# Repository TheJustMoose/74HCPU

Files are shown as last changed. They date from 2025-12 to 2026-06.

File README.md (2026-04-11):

# 74HCPU

Not a very scary instruction set discrete logic processor.

* 8 bit data
* 16 bit address / 64KB RAM
* 17 bit address (in V register) / 128KW Dual Bank Video RAM
* 16 [instructions](#instruction-list)
* 8 data [registers](#registers) and 4 pointer registers in 2 banks
* 1 [flags register](#flags-register) in IO port
* 32 input ports and 32 output ports (You can write a constant to the first 8 ports. Only registers can be written to the remaining ports.)
* Assembled from 74HCxx series ICs!

## Soft!
[ASM](./ASM.md)
[UEMUL]()

## CPU structure
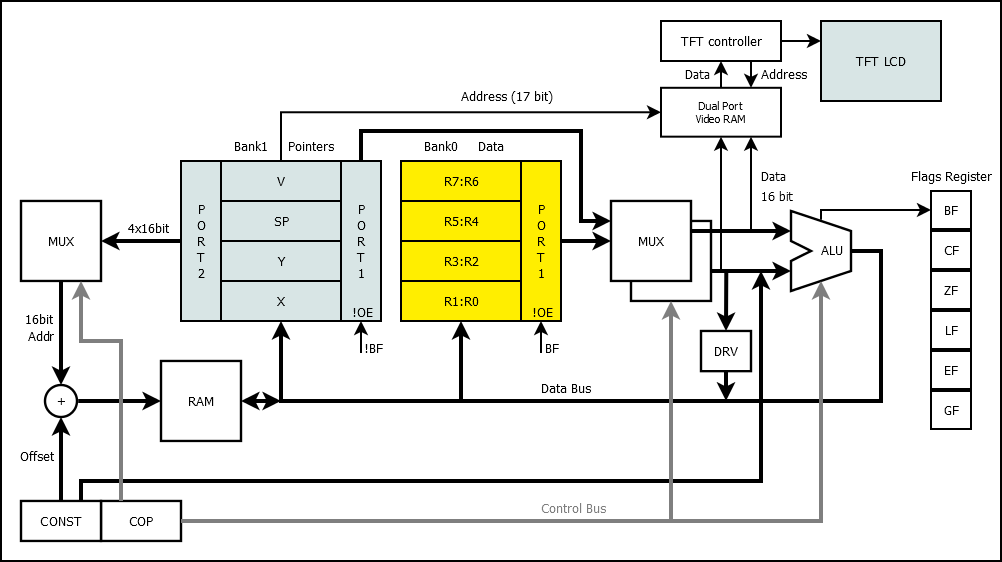
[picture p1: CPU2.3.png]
CPU structure


## How this CPU works?

CPU tacts

[Layers of PCBs](layers/README.md)

## Instruction list
*The words 'instruction' and 'command' mean the same thing.*

```
|----------------------------------------------|f|-------------------------------------------------------------|
|   HIGH BYTE    |    LOW BYTE   |  HIGH BYTE  |l|                                                             |
|F E D C  B A 9 8 7 6 5 4 3 2 1 0|   (again)   |a|                    SHORT DESCRIPTION                        |
|   4   +   3 + 1 + 3  +    5    = 16          |g|                                                             |
|----------------------------------------------|s|-------------------------------------------------------------|
|   ADD |  DST |1|    CONST or   | 01 0000 0001|*| Add a constant to a register (This is one command, not two) |
|   ADD |  DST |0| SRC |-|Z|z|I|i| 00 0000 0000|*| Add a register to a register (same OpCode, different bit 8) |
|----------------------------------------------| |-------------------------------------------------------------|
|  ADDC |  DST |C| SRC |F|Z|z|I|i| 10 0001 0000|*| ADD a constant or register and CARRY FLAG to a register     |
|   AND |  DST |C| SRC |-|Z|z|I|i| 20 0010 0000|*| Bitwise AND a constant or register with a register          |
|    OR |  DST |C| SRC |-|Z|z|I|i| 30 0011 0000|*| Bitwise OR a constant or register with a register           |
|   XOR |  DST |C| SRC |-|Z|z|I|i| 40 0100 0000|*| Bitwise XOR a constant or register with a register          |
|   MUL |  DST |C| SRC |-|Z|z|I|i| 50 0101 0000|*| MULtiply a constant or register by a register.              |
|   UNO |  DST |0|-|TYP|F|-|-|-|-| 60 0110 0000|*| Unary commands INV, SWAP, LSR, LSRC                         |
|   MOV |  DST |C| SRC |*|Z|z|I|i| 70 0111 0000| | MOV a constant or register to a register                    |
|   LPM |  DST |0|EXT|D|U|-|-|-|W| 80 1000 0000| | Load Program Memory - Read data from [commands] ROM         |
|    LD |  DST |V|EXT|D|U|OFFSET4| 90 1001 0000| | LoaD data from RAM to a register                            |
|    IN |  DST |  PORT   |Z|z|I|i| A0 1010 0000| | INput data from port to a register                          |
|--------------|8-7-6-5-4|-------|-------------| |-------------------------------------------------------------|
|   OUT | PORT |1|    CONST or   | B1 1011 0001| | Output const to a port (This is one command, not two)       |
|   OUT | PORT |0| SRC |PRT|X|O|o| B0 1011 0000| | Output register to a port (same OpCode, different bit 8)    |
|----------------------------------------------| |-------------------------------------------------------------|
|    ST |  SRC |V|EXT|D|U|OFFSET4| C0 1100 0000| | STore a register to a RAM                                   |
|   CMP |  DST |C| SRC |-|   -   | D0 1101 0000|+| CoMPare a constant or register with a register              |
|  CMPC |  DST |C| SRC |-|   -   | E0 1110 0000|+| Check flags then execute CMP                                |
| BRNCH |  CALL  | 8 bit OFFSET  | F0 1111 0000| | CALL a function with a relative address (offset)            |
| BRNCH |   JMP  | 8 bit OFFSET  | F1 1111 0001| | JMP to a relative address                                   |
| BRNCH |   RET  | 8 bit +STACK  | F2 1111 0010| | RETurn from function                                        |
| BRNCH |  RETI  | 8 bit OFFSET  | F3 1111 0011| | RETurn from Interrupt                                       |
| BRNCH |    JL  | 8 bit OFFSET  | F4 1111 0100| | Jump if Less                                                |
| BRNCH |    JE  | 8 bit OFFSET  | F5 1111 0101| | Jump if Equal                                               |
| BRNCH |   JNE  | 8 bit OFFSET  | F6 1111 0110| | Jump if Not Equal                                           |
| BRNCH |    JG  | 8 bit OFFSET  | F7 1111 0111| | Jump if greater                                             |
| BRNCH |    JZ  | 8 bit OFFSET  | F8 1111 1000| | Jump if Zero                                                |
| BRNCH |   JNZ  | 8 bit OFFSET  | F9 1111 1001| | Jump If Not Zero                                            |
| BRNCH |    JC  | 8 bit OFFSET  | FA 1111 1010| | Jump if Carry flag is set (one)                             |
| BRNCH |   JNC  | 8 bit OFFSET  | FB 1111 1011| | Jump if Carry flag is not set (zero)                        |
| BRNCH |   JHC  | 8 bit OFFSET  | FC 1111 1100| | Jump if Half Carry is set (one)                             |
| BRNCH |  JNHC  | 8 bit OFFSET  | FD 1111 1101| | Jump if Half Carry is not set (zero)                        |
| BRNCH | AFCALL | Hi 8 bit ADDR | FE 1111 1110| | Absolute Far Call (call a function at a 16-bit address)     |
| BRNCH |NOP/STOP|   1111 111x   | FF 1111 1111| | No OPeration (LSB is 0) or STOP CPU (LSB is 1)              |
|----------------------------------------------|-|-------------------------------------------------------------|
```
\* - means ZF, CF, HCF [flags](#flags-register), \+ - means GF, EQ, LF flags

### Registers
74HCPU has two register banks.
First bank has 8 arithmetic registers.
Second bank has 4 pointers (which can be used as 8 arithmetic registers).
You can change the active bank by writing BF bit of the [flags register](#flags-register).

#### Bank0 (8 pcs 8 bits registers):
|Name|Name|
|---|---|
|R7|R6|
|R5|R4|
|R3|R2|
|R1|R0|

#### Bank1 (4 pcs 16 bit registers):
<table>
<tr>
<td>

|Name|Usage|
|---|---|
|V|Video Pointer (**17** bits)|
|SP|Stack Pointer (16 bits)|
|Y|Pointer 1 (16 bits), e.g. Destination|
|X|Pointer 0 (16 bits), e.g. Source|
16 bit pointers
</td>
<td>

|Name|Name|
|---|---|
|VH|VL|
|SPH|SPL|
|YH|YL|
|XH|XL|
or 8 bit registers
</td></tr>
</table>

Also, you can use the registers of bank 1 in the same way as bank 0: R0, R1, ... R7
(R7 will store the high half of SP, R6 the low half).

### Flags register
|Bit|Flag Name|Usage|Reason|
|---|---|---|---|
|7|-|reserved|-|
|6|BF|Bank|You can write it|
|5|GF|Greater|Compare (CMP)|
|4|~EQ|Equal (inverted)|Compare (CMP)|
|3|LF|Less|Compare (CMP)|
|2|ZF|Zero|Arithmetic|
|1|CF|Carry|Arithmetic|
|0|HCF|Half Carry|Arithmetic|

### ADD, ADDC, AND, OR, XOR, MUL are binary commands  
You can use it:  
CMD Rd, Rs  
Where Rd is destination register.  
And Rs is source register.  
These commands work like this:  
Rd := Rd CMD Rs  
For example, ADD command does this:  
ADD R0, R1 -> R0 := R0 + R1  
Also you can use immediate value:  
CMD Rd, CONST  
(You can use CONST with any command: ADD, ADDC, AND, OR, XOR, MUL, MOV...)

The only exception to the use of the Rd register is MUL command.  
A pair of registers is needed to store the multiplication results.  
For example:  
MUL R1, R2 will store result into R1:R0 pair.  
That is, R1:R0 := R1 * R2.

### MUL Examples
```
  Rd select output Pair:
      _________
  Rd /         \ Pair   Rd   Rs
     |         \/
MUL R0, R1 -> R1:R0  := R0 * R1
MUL R1, R0 -> R1:R0  := R1 * R0
MUL R1, R2 -> R1:R0  := R1 * R2
MUL R1, R7 -> R1:R0  := R1 * R7
MUL R2, R3 -> R3:R2  := R2 * R3
MUL R2, R7 -> R3:R2  := R2 * R7
....
```

#### Register pairs  
The MUL command uses the following register pairs to store result:  
R1:R0 (when Rd is R0 or R1)  
R3:R2 (when Rd is R2 or R3)  
R5:R4 (when Rd is R4 or R5)  
R7:R6 (when Rd is R6 or R7)  
Rd is used to select output register pair.

### Instruction options  
C - Low byte [of command] contains constant value (1) or options (0).  
Z - Will reset high nibble of SRC register before use.  
z - Will reset low nibble of SRC register before use.  
I - Will invert high nibble of SRC register before use.  
i - Will invert low nibble of SRC register before use.  
F - Set CF flag to TRUE while executing command.  
W - Command will work with word, not byte.  
V - Command will work with Video RAM.  
D - Down, decrease pointer after command.  
U - Up, increase pointer after command.  
OFFSET4 - 4 bit size int offset to current pointer.  
O - Out will write to high nibble of port.  
o - Out will write to low nibble of port.  
X - Out will toggle bits of port by mask in register.  
SRC - Index of source register (0-7).  
DST - Index of destination register (0-7).  
TYP - Kind of unary operation (0-3).  
EXT - Index of pointer register (0-3).  
PORT + PRT - 5 bit of port index.

### UNO - unary commands  
There are four unary commands: LSR, LSRC, INV, SWAP.  
LSR shift register bits to the right. CF flag get value of right (low) bit.  
LSRC do same, but left (high) bit get value of CF.  
SWAP simply swap the nibbles.  
INV simply invert all the bits.

### LPM - Load Program Memory  
This command read (1 byte of) data from ROM, not RAM. And this command write data to register.  
The data stores in the same ROM that stores the commands themselves.
Also you can use LPMW to read the whole 16 bit word from ROM and store data to [register pair](#register-pairs).

### LD, ST - Memory commands  
LD - LoaD data from memory  
ST - STore data to memory  
V - 0 for RAM and 1 for Video RAM  
SRC - register to read  
DST - register to write  
EXT - register pair which store pointer to memory  
D - Decrement pointer after use  
U - Increment pointer after use  
OFFSET4 - 4 bit integer offset (-8...+7)  
(CPU will read/write memory with address ptr(EXT) + OFFSET4)  
Examples:
```
LD R0, X    ; read memory data from X pointer into the R0 register
ST Y, R1    ; write data from R1 into memory with address from Y pointer
ST YI, R1   ; write data and increment Y pointer
ST YD, R1   ; write data and decrement Y pointer
ST Y+5, R1  ; write data into memory address Y+5
LDV R7, V   ; read data from Video RAM with address V and store it into R7 (R7:R6 pair)
LDV R7, V+1 ; **disabled** command, you can use displacement only with X, Y and SP pointers
```

### BRNCH - Branch commands  
CALL - call a function by offset  
AFCALL - call a function to an absolute address  
RET - return to the address stored on the stack  
RETI - return from interrupt to the address stored on the stack  
JMP - go by offset  
NOP - no operation (do nothing)  
STOP - the processor will stop executing the program  
JL, JE, JNE, JG, JZ, JNZ, JC, JNC, JHC, JNHC - conditional jump instructions  
JL - jump if less  
JE - jump if equal  
JNE - jump if not equal  
JG - jump if greater  
JZ - jump if zero  
JNZ - jump if not zero  
JC - jump if carry  
JNC - jump if not carry  
JHC - jump if half carry  
JNHC - jump if not half carry

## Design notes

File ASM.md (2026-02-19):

# 74HCPU

## ASM

ASM is assembler for 74HCPU.
You can find it [here](https://github.com/TheJustMoose/74HCPU/tree/master/soft/asm).

74HCPU assembler is similar to Intel assembler.

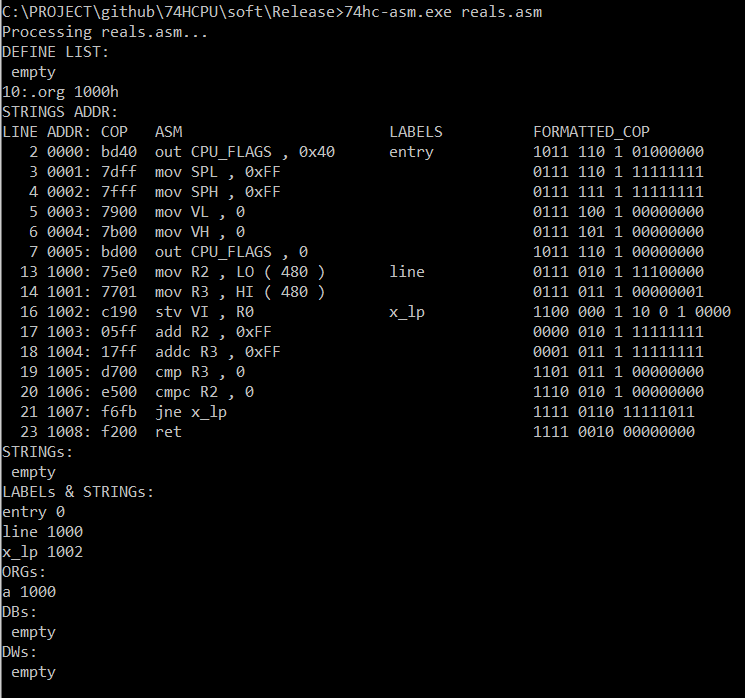
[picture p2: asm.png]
CPU asm console


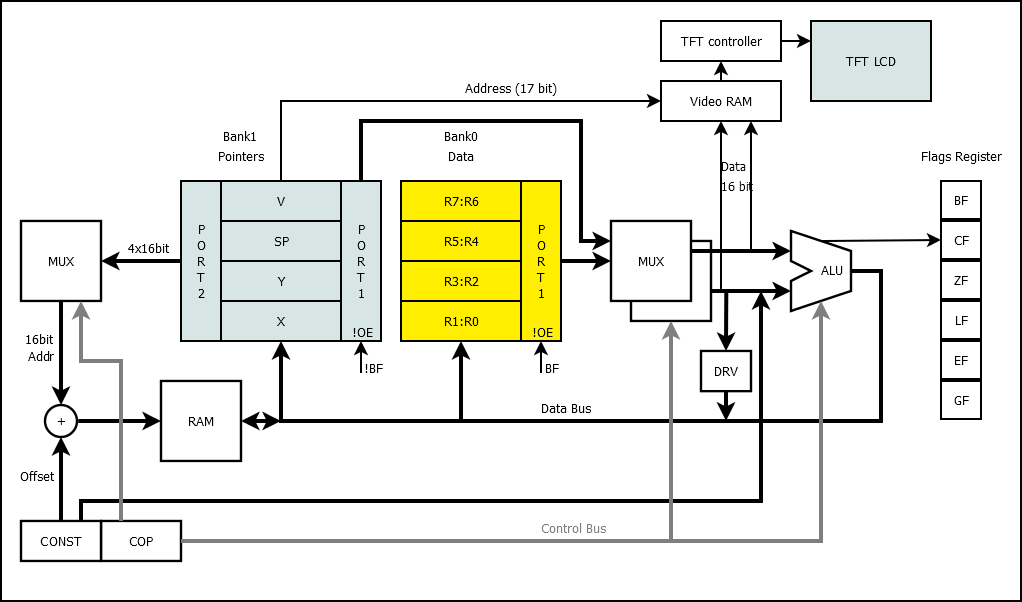
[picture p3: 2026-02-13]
CPU2.2.png

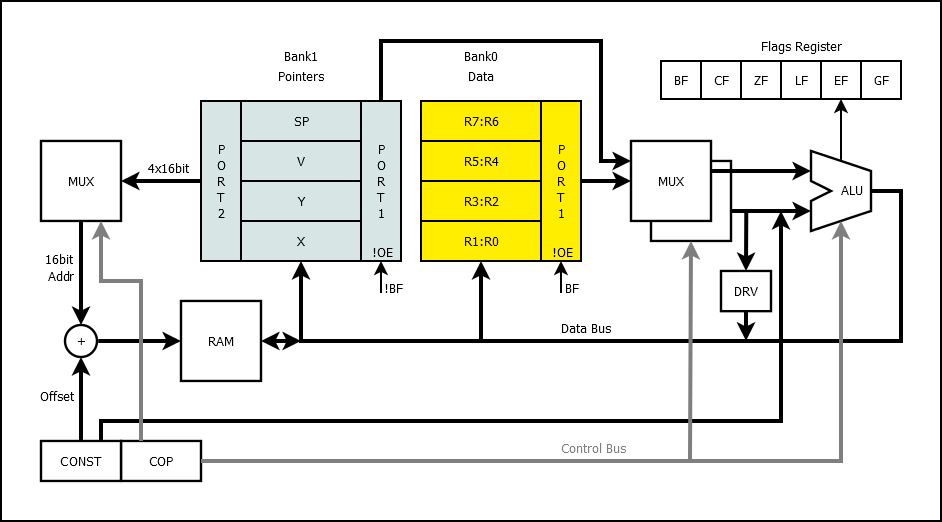
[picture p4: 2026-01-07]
CPU2.1.png

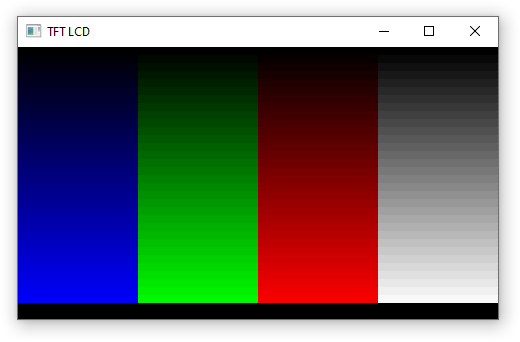
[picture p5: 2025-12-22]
soft/uemul/lcd/scr.png

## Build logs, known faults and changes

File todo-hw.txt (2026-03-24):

!!!!спаять уже всё нахрен!!!!

блин! я же совсем забыл о том, что стек то у меня есть,
 а вот счётчиков/мультиплексоров для выбора, какую ячейку читать/писать,
 я так и не дорисовал на плате
 (и триггер для фиксации stack overflow тоже нужен)

переделать MUX8:1 1bit, поменять порядок входов D0...D7
 ну и разъёмы из середины перенести в торец, чтобы избавиться от проводов

сделать торцевую плату для однобитных мультиплексоров

сделать плату для рубильников (на 8 бит)

сделать новый вариант регистра-счётчика на 8+ бит
 (хотя бы на 9, или сразу на 12, иначе выводить видео хз как)

поставить хотя бы один эксперимент с gLCD,
 например вывести на него ОДИН одноцветный прямоугольник на всю его площадь ;)

поиграть с Dual Port Video RAM

начать рисовать плату для gLCD
 (накидать туда хотя бы разъём gLCD, счётчики, генераторы)

переделать MUX2:1 так, чтобы оба входа располагались не по горизонтали, а по вертикали
         H_in     L_in     Out
 было  ........ ........ ........

         H_in     Out
 стало ........ ........
       ........
         L_in

купить запас мультиплексоров

проверить, что разъёмы плат удобно расположены

переделать плату ROM, чтобы туда намертво запаивался ZIF сокет,
 и не нужно было втыкать в разъёмы на плате переходник ZIF -> DIP,
 а уже в переходник саму ROM

начать рисовать прерывания
предусмотреть два регистра флагов - для обычной работы и работы в ISP

попробовать поковырять UART0, для начала хотя бы в виде микросхемы + Arduino!

придумать что-то с таблицей виртуальных методов,
 например сделать ICALL, или RCALL, или хз,
 как вызвать код по индексу в таблице, которая лежит в ROM
 в общем, проверить как-то, что у меня заведено в мультиплексор адреса
 (и какой вообще адрес он мультиплексирует)

условно: есть некая таблица, которая лежит в ROM
в ней есть:
addr0 - адрес виртуального метода 0
addr1 - адрес виртуального метода 1
.....

таких табличек много
адрес таблички, видимо, должен лежать в ...? в RAM, рядом со всеми данными объекта класса?
или где-то в ROM? ведь адрес таблицы не меняется после компиляции...
хотя, если есть наследование, то адрес как раз должен меняться
Оо

в любом случае, чтобы вызвать функцию/метод по индексу в табличке, можно сделать:
 берём адрес начала таблицы,
 прибавляем к нему индекс,
 читаем из этого адреса 16 бит,
 считаем эти 16 бит адресом, вызываем метод по этому адресу

альтернатива:
 располагаем перед таблицей код, который делает CALL, как раз по смещению, относительно себя
 .... а толку?

а как должен работать ICALL? брать адрес из какого-нибудь регистра?

кстати, в таблице можно располагать не абсолютные адреса,
 а саму команду CALL... и делать на эту команду JMP
  вот только не понятно, как это сделать :(

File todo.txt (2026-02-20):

ZF должен защёлкиваться по арифметическим командам, а не по CMPx
потерялись светодиоды индикации банков

проверить размер микросхем на плате регистра
проверить размер фрезы во фьюжене на плате регистра, поменять на 0.9
протравить пару регистров
набить пару регистров
набить и протестировать плату регистров
купить текстолита и лужёного провода
собрать новый фрезерный станок
купить новый монитор помельче
попробовать фрезернуть мелкую плату прям по контуру дорожек
 (только нету фрезы 0.5)
кажется, у АЛУ нет подключения шинного формирователя к BUS для команды OUT
добавить на плату АЛУ типа монтажку, ибо наверняка какой-нибудь микросхемы не хватит
добавить подписей пинов на плату АЛУ
собрать уже наконец пульт управления для проца

нарисовать свежих монтажек, с Т образным расположением площадок
(два размера, для мелких плат с флагами и для ROM)
+написать ассемблер
+написать отладчик
начать рисовать в KiCAD схемы модулей

+Proto50x70-4er
+Proto100x150
+Proto100x150-4er

07.11.2022:
+набить платы AND/OR/XOR
+набить платы MUX4:1
+пересобрать проц и протестировать
 (в результате должно стать больше места и меньше багов)
+нарисовать/заказать платы AND&ADD
 (а также новые MUX4:1 и RegLED, регистр флагов?)
+протравить/набить платы RegLED
переделать монтажку регистров на 4 платы
набить плату RegLED
+сделать плату LCD, поставить на освободившееся место!
+протравить/набить плату CMP
что-то сделать с оставшимися платами INV, MOV
+начать собирать регистр флагов на освободившемся месте
+переделать команды условных переходов О_О
добавить команды SWAP, SHL, SHR
+что-то придумать с хранением бита переноса
сделать стек поглубже
придумать уже подходящий код для тестирования!
+получить платы AND&ADD и сделать уже умножение! :))
поменять LCD 1602 на gLCD
протестировать максимальную частоту *ROFL*

перенести на плату ROM?
+перейти на 12бит коды операций? уже, фактически, 16 битные
+сделать MUX8:1?
добавить команд вычитания и т.п.?

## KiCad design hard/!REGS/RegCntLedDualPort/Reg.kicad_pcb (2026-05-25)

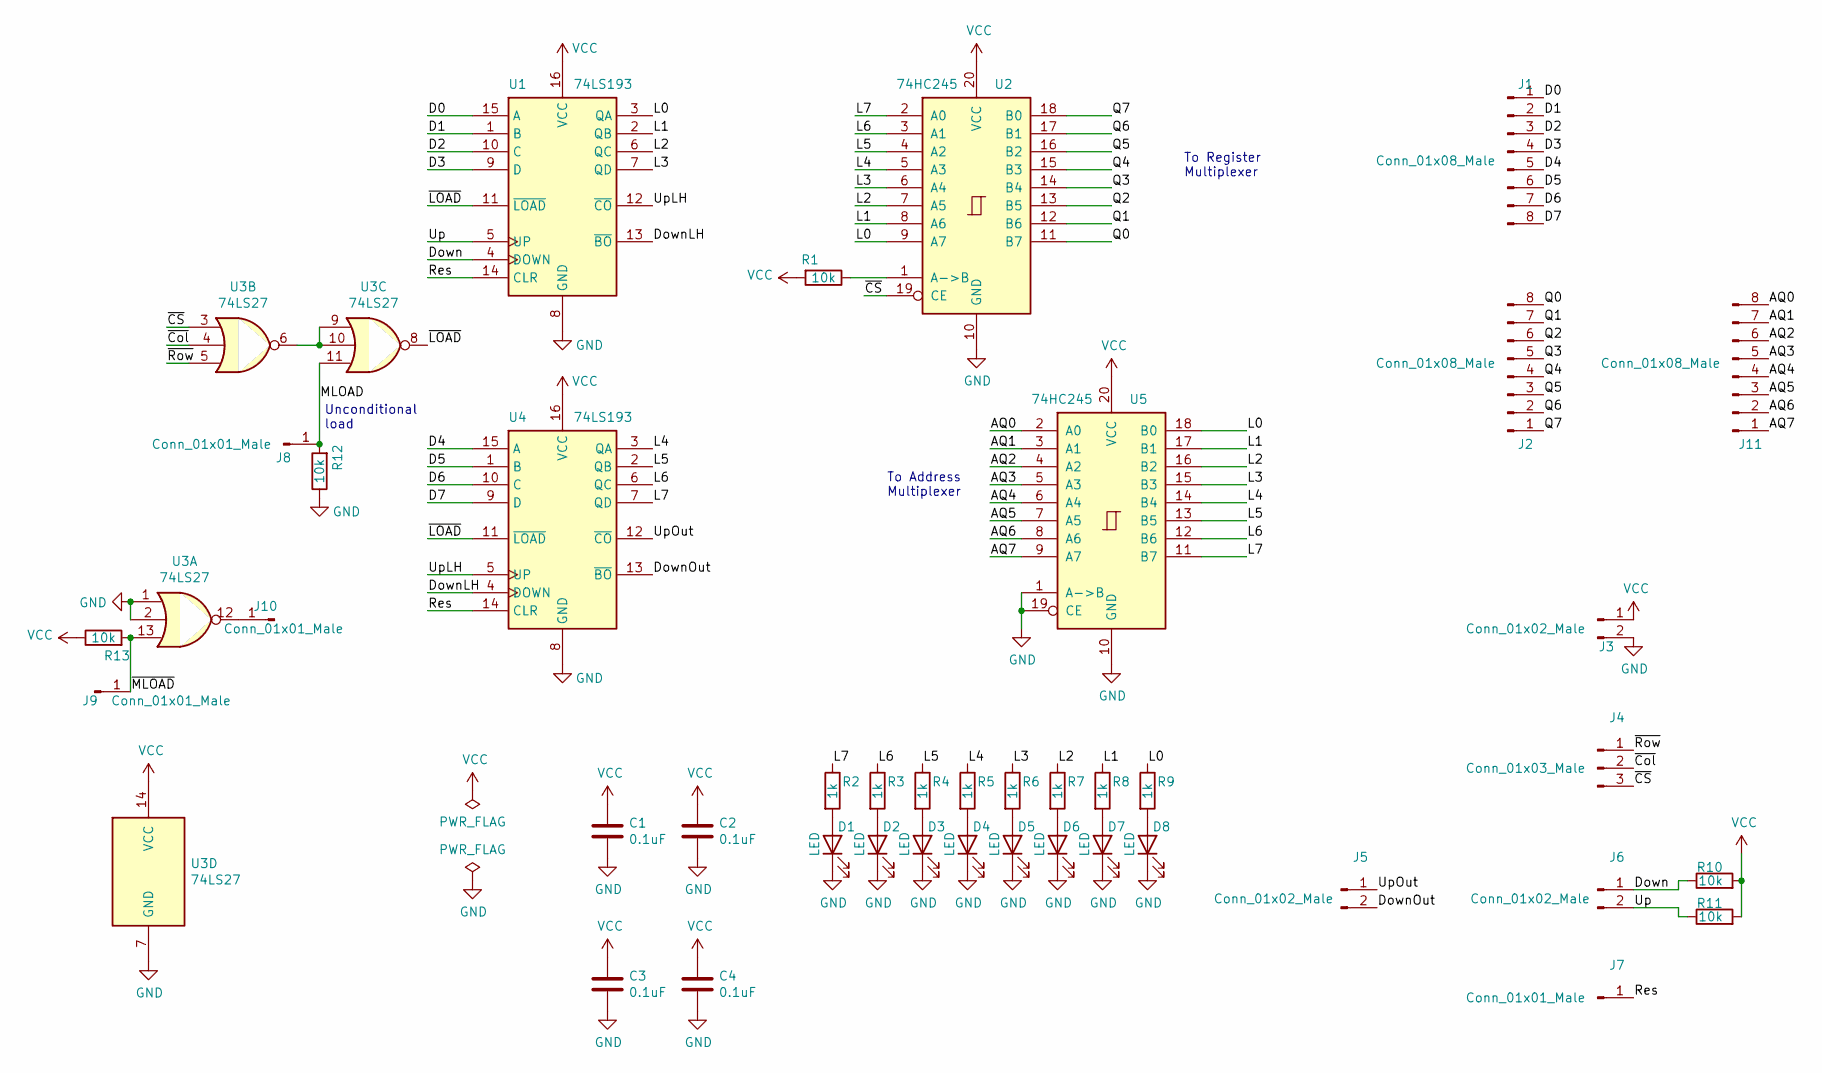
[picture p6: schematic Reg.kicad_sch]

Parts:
C1, C3: 0.1uF; C_Axial_L3.8mm_D2.6mm_P12.50mm_Horizontal
C2, C4: 0.1uF; C_0805_2012Metric_Pad1.18x1.45mm_HandSolder
D1, D2, D3, D4, D5, D6, D7, D8: LED; LED_0805_2012Metric_Pad1.15x1.40mm_HandSolder
J1, J2, J11: Conn_01x08_Male; PinHeader_1x08_P2.54mm_Horizontal
J3, J5, J6: Conn_01x02_Male; PinHeader_1x02_P2.54mm_Horizontal
J4: Conn_01x03_Male; PinHeader_1x03_P2.54mm_Horizontal
J7, J8, J9, J10: Conn_01x01_Male; PinHeader_1x01_P2.54mm_Horizontal
R1, R10, R11, R12, R13: 10k; R_0805_2012Metric_Pad1.20x1.40mm_HandSolder
R2, R3, R4, R5, R6, R7, R8, R9: 1k; R_0805_2012Metric_Pad1.20x1.40mm_HandSolder
U1, U4: 74LS193; SOP-16_3.9x9.9mm_P1.27mm
U2, U5: 74HC245; SOP-20_7.5x12.8mm_P1.27mm
U3: 74LS27; SO-14_3.9x8.65mm_P1.27mm

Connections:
/AQ0: J11.8, U5.2 (A0)
/AQ1: J11.7, U5.3 (A1)
/AQ2: J11.6, U5.4 (A2)
/AQ3: J11.5, U5.5 (A3)
/AQ4: J11.4, U5.6 (A4)
/AQ5: J11.3, U5.7 (A5)
/AQ6: J11.2, U5.8 (A6)
/AQ7: J11.1, U5.9 (A7)
/D0: J1.1, U1.15 (A)
/D1: J1.2, U1.1 (B)
/D2: J1.3, U1.10 (C)
/D3: J1.4, U1.9 (D)
/D4: J1.5, U4.15 (A)
/D5: J1.6, U4.1 (B)
/D6: J1.7, U4.10 (C)
/D7: J1.8, U4.9 (D)
/Down: J6.1, R10.1, U1.4 (DOWN)
/DownLH: U1.13 (~BO), U4.4 (DOWN)
/DownOut: J5.2, U4.13 (~BO)
/L0: R9.1, U1.3 (QA), U2.9 (A7), U5.18 (B0)
/L1: R8.1, U1.2 (QB), U2.8 (A6), U5.17 (B1)
/L2: R7.1, U1.6 (QC), U2.7 (A5), U5.16 (B2)
/L3: R6.1, U1.7 (QD), U2.6 (A4), U5.15 (B3)
/L4: R5.1, U2.5 (A3), U4.3 (QA), U5.14 (B4)
/L5: R4.1, U2.4 (A2), U4.2 (QB), U5.13 (B5)
/L6: R3.1, U2.3 (A1), U4.6 (QC), U5.12 (B6)
/L7: R2.1, U2.2 (A0), U4.7 (QD), U5.11 (B7)
/MLOAD: J8.1, R12.2, U3.11
/Q0: J2.8, U2.11 (B7)
/Q1: J2.7, U2.12 (B6)
/Q2: J2.6, U2.13 (B5)
/Q3: J2.5, U2.14 (B4)
/Q4: J2.4, U2.15 (B3)
/Q5: J2.3, U2.16 (B2)
/Q6: J2.2, U2.17 (B1)
/Q7: J2.1, U2.18 (B0)
/Res: J7.1, U1.14 (CLR), U4.14 (CLR)
/Up: J6.2, R11.1, U1.5 (UP)
/UpLH: U1.12 (~CO), U4.5 (UP)
/UpOut: J5.1, U4.12 (~CO)
/~CS: J4.3, U2.19 (CE), U3.3
/~Col: J4.2, U3.4
/~LOAD: U1.11 (~LOAD), U3.8, U4.11 (~LOAD)
/~MLOAD: J9.1, R13.2, U3.13
/~Row: J4.1, U3.5
GND: C1.2, C2.2, C3.2, C4.2, D1.1 (K), D2.1 (K), D3.1 (K), D4.1 (K), D5.1 (K), D6.1 (K), D7.1 (K), D8.1 (K), J3.2, R12.1, U1.8 (GND), U2.10 (GND), U3.1, U3.2, U3.7 (GND), U4.8 (GND), U5.1 (A->B), U5.10 (GND), U5.19 (CE)
unnamed: D1.2 (A), R2.2
unnamed: D2.2 (A), R3.2
unnamed: D3.2 (A), R4.2
unnamed: D4.2 (A), R5.2
unnamed: D5.2 (A), R6.2
unnamed: D6.2 (A), R7.2
unnamed: D7.2 (A), R8.2
unnamed: D8.2 (A), R9.2
unnamed: J10.1, U3.12
unnamed: R1.1, U2.1 (A->B)
unnamed: U3.6, U3.9, U3.10
VCC: C1.1, C2.1, C3.1, C4.1, J3.1, R1.2, R10.2, R11.2, R13.1, U1.16 (VCC), U2.20 (VCC), U3.14 (VCC), U4.16 (VCC), U5.20 (VCC)

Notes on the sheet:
To Register Multiplexer
To Address Multiplexer
Unconditional load

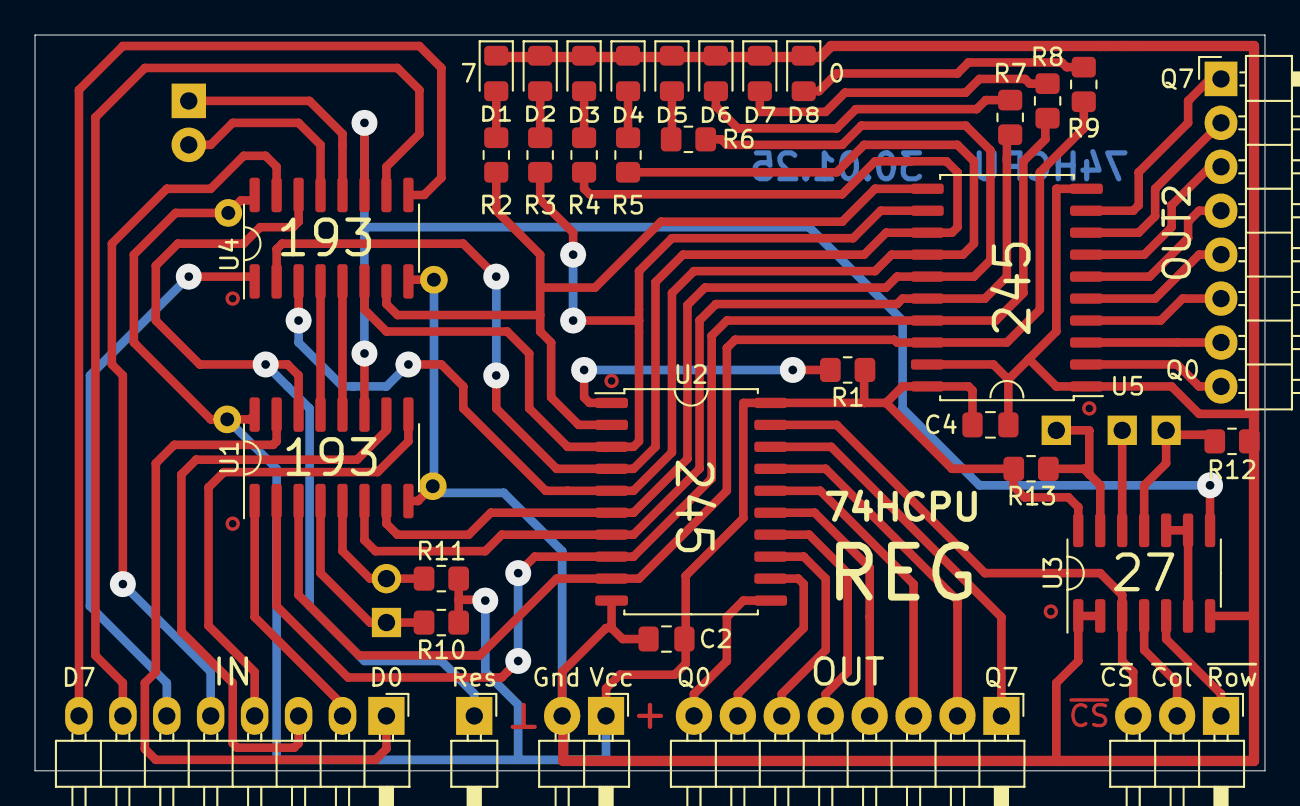
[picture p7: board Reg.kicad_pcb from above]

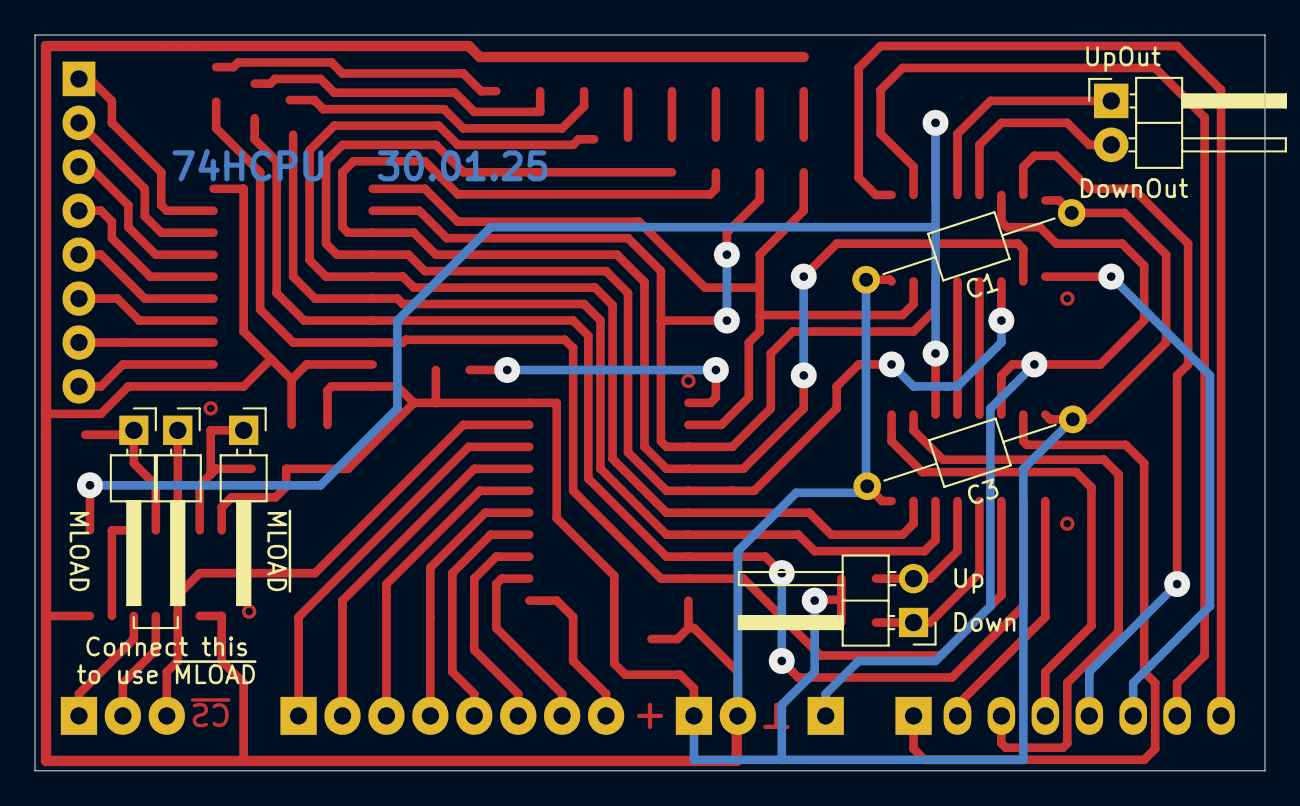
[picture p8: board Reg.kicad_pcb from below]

Board: 2 copper layers, 71.1 x 42.5 mm, 41 parts (7 on the bottom side), 58 nets.

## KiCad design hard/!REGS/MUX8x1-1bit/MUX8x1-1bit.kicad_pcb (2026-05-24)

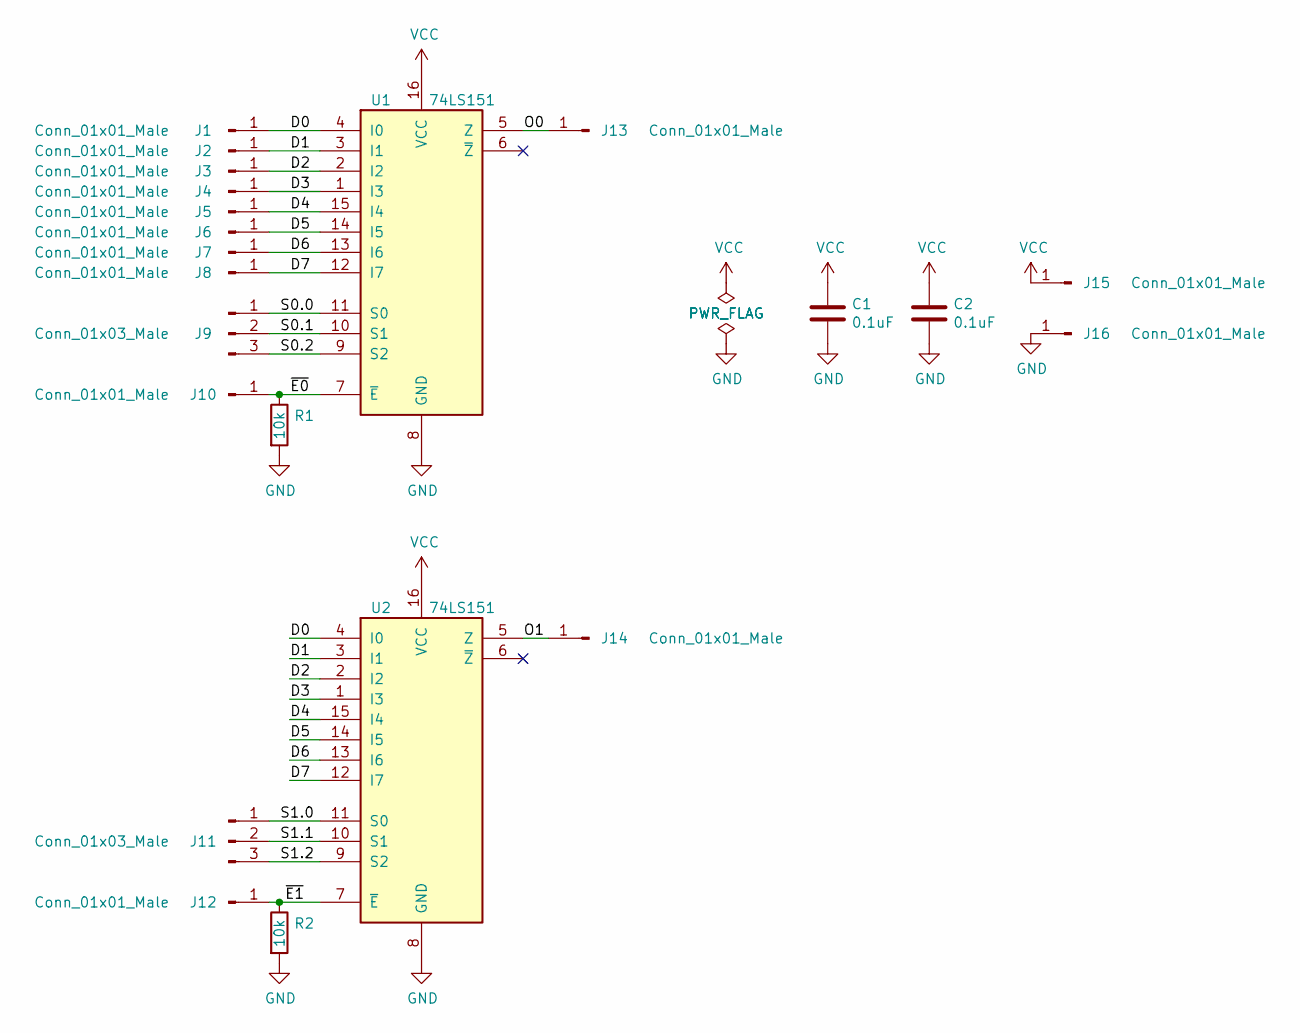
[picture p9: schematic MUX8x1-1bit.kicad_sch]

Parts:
C1, C2: 0.1uF; C_0805_2012Metric_Pad1.18x1.45mm_HandSolder
J1, J2, J3, J4, J5, J6, J7, J8, J10, J12, J13, J14, J15, J16: Conn_01x01_Male; PinHeader_1x01_P2.54mm_Horizontal
J9, J11: Conn_01x03_Male; PinHeader_1x03_P2.54mm_Horizontal
R1, R2: 10k; R_0805_2012Metric_Pad1.20x1.40mm_HandSolder
U1, U2: 74LS151; SO-16_3.9x9.9mm_P1.27mm

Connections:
/D0: J1.1, U1.4 (I0), U2.4 (I0)
/D1: J2.1, U1.3 (I1), U2.3 (I1)
/D2: J3.1, U1.2 (I2), U2.2 (I2)
/D3: J4.1, U1.1 (I3), U2.1 (I3)
/D4: J5.1, U1.15 (I4), U2.15 (I4)
/D5: J6.1, U1.14 (I5), U2.14 (I5)
/D6: J7.1, U1.13 (I6), U2.13 (I6)
/D7: J8.1, U1.12 (I7), U2.12 (I7)
/O0: J13.1, U1.5 (Z)
/O1: J14.1, U2.5 (Z)
/S0.0: J9.1, U1.11 (S0)
/S0.1: J9.2, U1.10 (S1)
/S0.2: J9.3, U1.9 (S2)
/S1.0: J11.1, U2.11 (S0)
/S1.1: J11.2, U2.10 (S1)
/S1.2: J11.3, U2.9 (S2)
/~E0: J10.1, R1.1, U1.7 (~E)
/~E1: J12.1, R2.1, U2.7 (~E)
GND: C1.2, C2.2, J16.1, R1.2, R2.2, U1.8 (GND), U2.8 (GND)
VCC: C1.1, C2.1, J15.1, U1.16 (VCC), U2.16 (VCC)

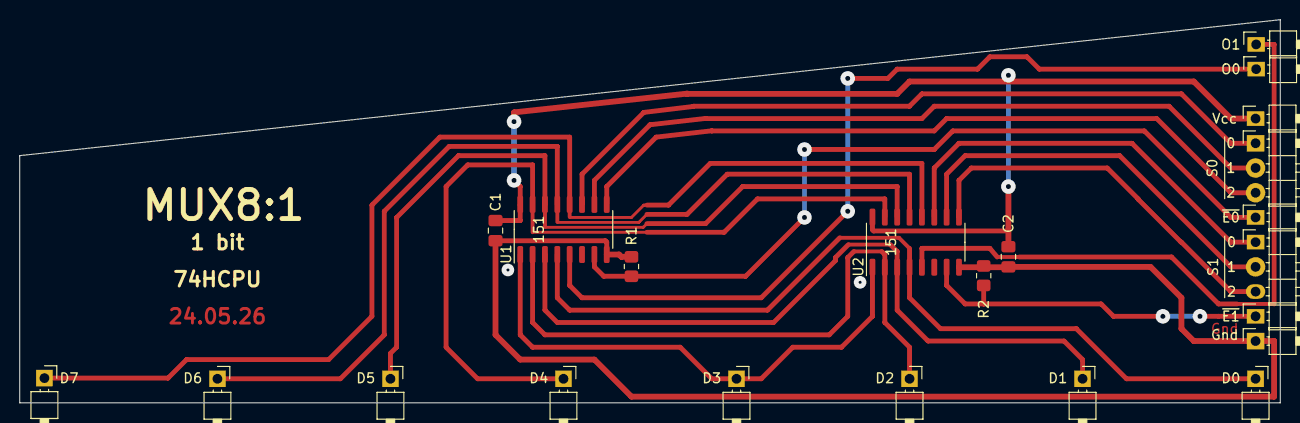
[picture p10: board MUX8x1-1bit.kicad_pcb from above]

Board: 2 copper layers, 129.5 x 39.4 mm, 22 parts (0 on the bottom side), 20 nets.

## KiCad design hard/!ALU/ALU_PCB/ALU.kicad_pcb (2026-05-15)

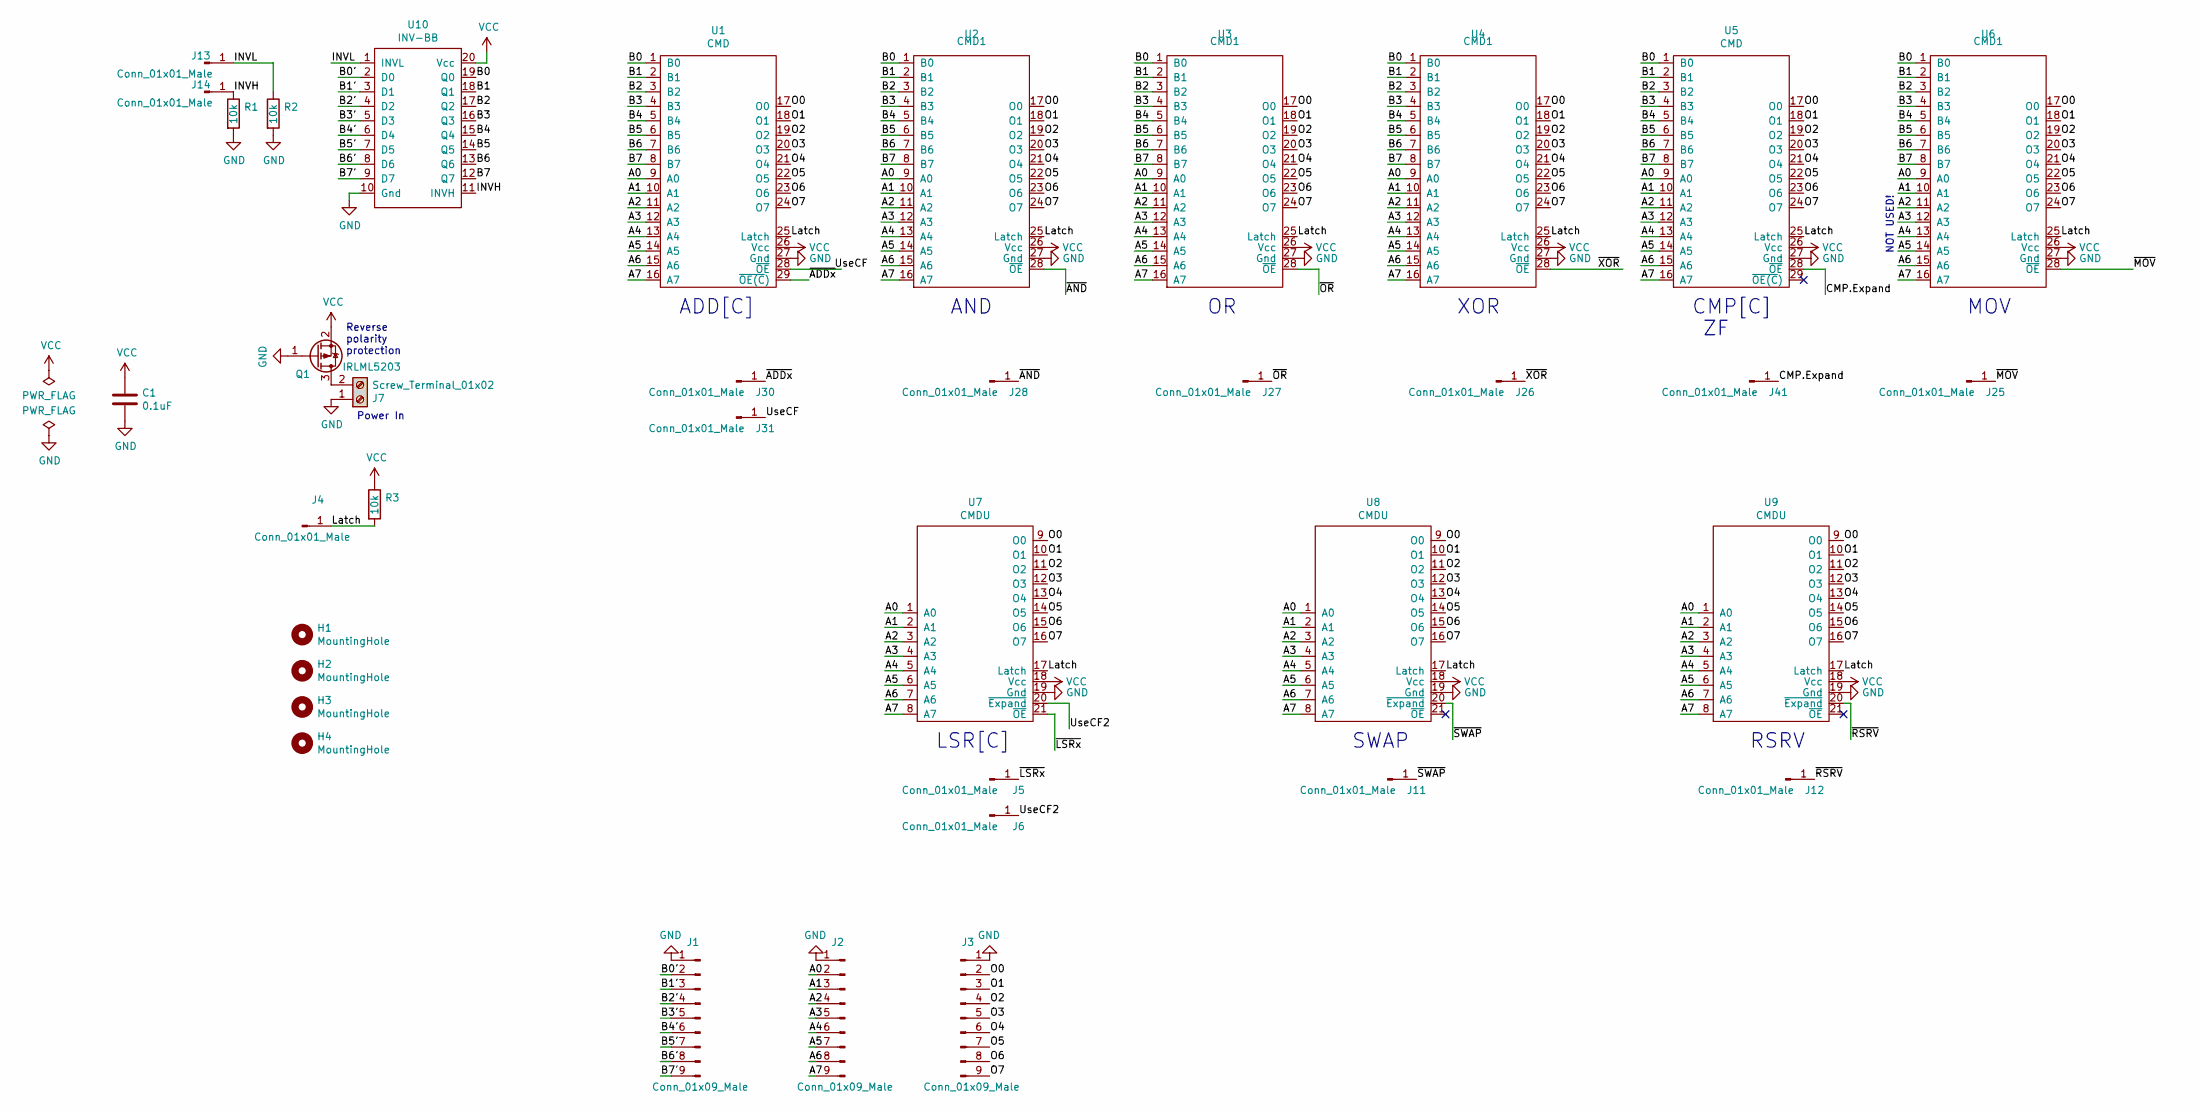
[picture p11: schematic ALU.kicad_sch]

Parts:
C1: 0.1uF; C_0805_2012Metric_Pad1.18x1.45mm_HandSolder
H1, H2, H3, H4: MountingHole; MountingHole_3.2mm_M3
J1, J2, J3: Conn_01x09_Male; PinHeader_1x09_P2.54mm_Vertical
J4, J5, J6, J11, J12, J13, J14, J25, J26, J27, J28, J30, J31, J41: Conn_01x01_Male; PinHeader_1x01_P2.54mm_Vertical
J7: Screw_Terminal_01x02; TerminalBlock_Phoenix_MKDS-1,5-2_1x02_P5.00mm_Horizontal
Q1: IRLML5203; SOT-23
R1, R2, R3: 10k; R_0805_2012Metric_Pad1.20x1.40mm_HandSolder
U1, U5: CMD
U2, U3, U4, U6: CMD1; CMDwoC
U7, U8, U9: CMDU
U10: INV-BB; INV-B

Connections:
/A0: J2.2, U1.9 (A0), U2.9 (A0), U3.9 (A0), U4.9 (A0), U5.9 (A0), U6.9 (A0), U7.1 (A0), U8.1 (A0), U9.1 (A0)
/A1: J2.3, U1.10 (A1), U2.10 (A1), U3.10 (A1), U4.10 (A1), U5.10 (A1), U6.10 (A1), U7.2 (A1), U8.2 (A1), U9.2 (A1)
/A2: J2.4, U1.11 (A2), U2.11 (A2), U3.11 (A2), U4.11 (A2), U5.11 (A2), U6.11 (A2), U7.3 (A2), U8.3 (A2), U9.3 (A2)
/A3: J2.5, U1.12 (A3), U2.12 (A3), U3.12 (A3), U4.12 (A3), U5.12 (A3), U6.12 (A3), U7.4 (A3), U8.4 (A3), U9.4 (A3)
/A4: J2.6, U1.13 (A4), U2.13 (A4), U3.13 (A4), U4.13 (A4), U5.13 (A4), U6.13 (A4), U7.5 (A4), U8.5 (A4), U9.5 (A4)
/A5: J2.7, U1.14 (A5), U2.14 (A5), U3.14 (A5), U4.14 (A5), U5.14 (A5), U6.14 (A5), U7.6 (A5), U8.6 (A5), U9.6 (A5)
/A6: J2.8, U1.15 (A6), U2.15 (A6), U3.15 (A6), U4.15 (A6), U5.15 (A6), U6.15 (A6), U7.7 (A6), U8.7 (A6), U9.7 (A6)
/A7: J2.9, U1.16 (A7), U2.16 (A7), U3.16 (A7), U4.16 (A7), U5.16 (A7), U6.16 (A7), U7.8 (A7), U8.8 (A7), U9.8 (A7)
/B0: U1.1 (B0), U2.1 (B0), U3.1 (B0), U4.1 (B0), U5.1 (B0), U6.1 (B0), U10.19 (Q0)
/B0': J1.2, U10.2 (D0)
/B1: U1.2 (B1), U2.2 (B1), U3.2 (B1), U4.2 (B1), U5.2 (B1), U6.2 (B1), U10.18 (Q1)
/B1': J1.3, U10.3 (D1)
/B2: U1.3 (B2), U2.3 (B2), U3.3 (B2), U4.3 (B2), U5.3 (B2), U6.3 (B2), U10.17 (Q2)
/B2': J1.4, U10.4 (D2)
/B3: U1.4 (B3), U2.4 (B3), U3.4 (B3), U4.4 (B3), U5.4 (B3), U6.4 (B3), U10.16 (Q3)
/B3': J1.5, U10.5 (D3)
/B4: U1.5 (B4), U2.5 (B4), U3.5 (B4), U4.5 (B4), U5.5 (B4), U6.5 (B4), U10.15 (Q4)
/B4': J1.6, U10.6 (D4)
/B5: U1.6 (B5), U2.6 (B5), U3.6 (B5), U4.6 (B5), U5.6 (B5), U6.6 (B5), U10.14 (Q5)
/B5': J1.7, U10.7 (D5)
/B6: U1.7 (B6), U2.7 (B6), U3.7 (B6), U4.7 (B6), U5.7 (B6), U6.7 (B6), U10.13 (Q6)
/B6': J1.8, U10.8 (D6)
/B7: U1.8 (B7), U2.8 (B7), U3.8 (B7), U4.8 (B7), U5.8 (B7), U6.8 (B7), U10.12 (Q7)
/B7': J1.9, U10.9 (D7)
/CMP.Expand: J41.1, U5.28 (~OE)
/INVH: J14.1, R1.1, U10.11 (INVH)
/INVL: J13.1, R2.1, U10.1 (INVL)
/Latch: J4.1, R3.2, U1.25 (Latch), U2.25 (Latch), U3.25 (Latch), U4.25 (Latch), U5.25 (Latch), U6.25 (Latch), U7.17 (Latch), U8.17 (Latch), U9.17 (Latch)
/O0: J3.2, U1.17 (O0), U2.17 (O0), U3.17 (O0), U4.17 (O0), U5.17 (O0), U6.17 (O0), U7.9 (O0), U8.9 (O0), U9.9 (O0)
/O1: J3.3, U1.18 (O1), U2.18 (O1), U3.18 (O1), U4.18 (O1), U5.18 (O1), U6.18 (O1), U7.10 (O1), U8.10 (O1), U9.10 (O1)
/O2: J3.4, U1.19 (O2), U2.19 (O2), U3.19 (O2), U4.19 (O2), U5.19 (O2), U6.19 (O2), U7.11 (O2), U8.11 (O2), U9.11 (O2)
/O3: J3.5, U1.20 (O3), U2.20 (O3), U3.20 (O3), U4.20 (O3), U5.20 (O3), U6.20 (O3), U7.12 (O3), U8.12 (O3), U9.12 (O3)
/O4: J3.6, U1.21 (O4), U2.21 (O4), U3.21 (O4), U4.21 (O4), U5.21 (O4), U6.21 (O4), U7.13 (O4), U8.13 (O4), U9.13 (O4)
/O5: J3.7, U1.22 (O5), U2.22 (O5), U3.22 (O5), U4.22 (O5), U5.22 (O5), U6.22 (O5), U7.14 (O5), U8.14 (O5), U9.14 (O5)
/O6: J3.8, U1.23 (O6), U2.23 (O6), U3.23 (O6), U4.23 (O6), U5.23 (O6), U6.23 (O6), U7.15 (O6), U8.15 (O6), U9.15 (O6)
/O7: J3.9, U1.24 (O7), U2.24 (O7), U3.24 (O7), U4.24 (O7), U5.24 (O7), U6.24 (O7), U7.16 (O7), U8.16 (O7), U9.16 (O7)
/UseCF: J31.1, U1.28 (~OE)
/UseCF2: J6.1, U7.20 (~Expand)
/~ADDx: J30.1, U1.29 (~OE(C))
/~AND: J28.1, U2.28 (~OE)
/~LSRx: J5.1, U7.21 (~OE)
/~MOV: J25.1, U6.28 (~OE)
/~OR: J27.1, U3.28 (~OE)
/~RSRV: J12.1, U9.20 (~Expand)
/~SWAP: J11.1, U8.20 (~Expand)
/~XOR: J26.1, U4.28 (~OE)
GND: C1.2, J1.1, J2.1, J3.1, J7.1, Q1.1 (G), R1.2, R2.2, U1.27 (Gnd), U2.27 (Gnd), U3.27 (Gnd), U4.27 (Gnd), U5.27 (Gnd), U6.27 (Gnd), U7.19 (Gnd), U8.19 (Gnd), U9.19 (Gnd), U10.10 (Gnd)
unnamed: J7.2, Q1.3 (D)
VCC: C1.1, Q1.2 (S), R3.1, U1.26 (Vcc), U2.26 (Vcc), U3.26 (Vcc), U4.26 (Vcc), U5.26 (Vcc), U6.26 (Vcc), U7.18 (Vcc), U8.18 (Vcc), U9.18 (Vcc), U10.20 (Vcc)

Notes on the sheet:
ADD[C]
Power In
MOV
RSRV
SWAP
NOT USED!
AND
XOR
Reverse polarity protection
CMP[C]
LSR[C]

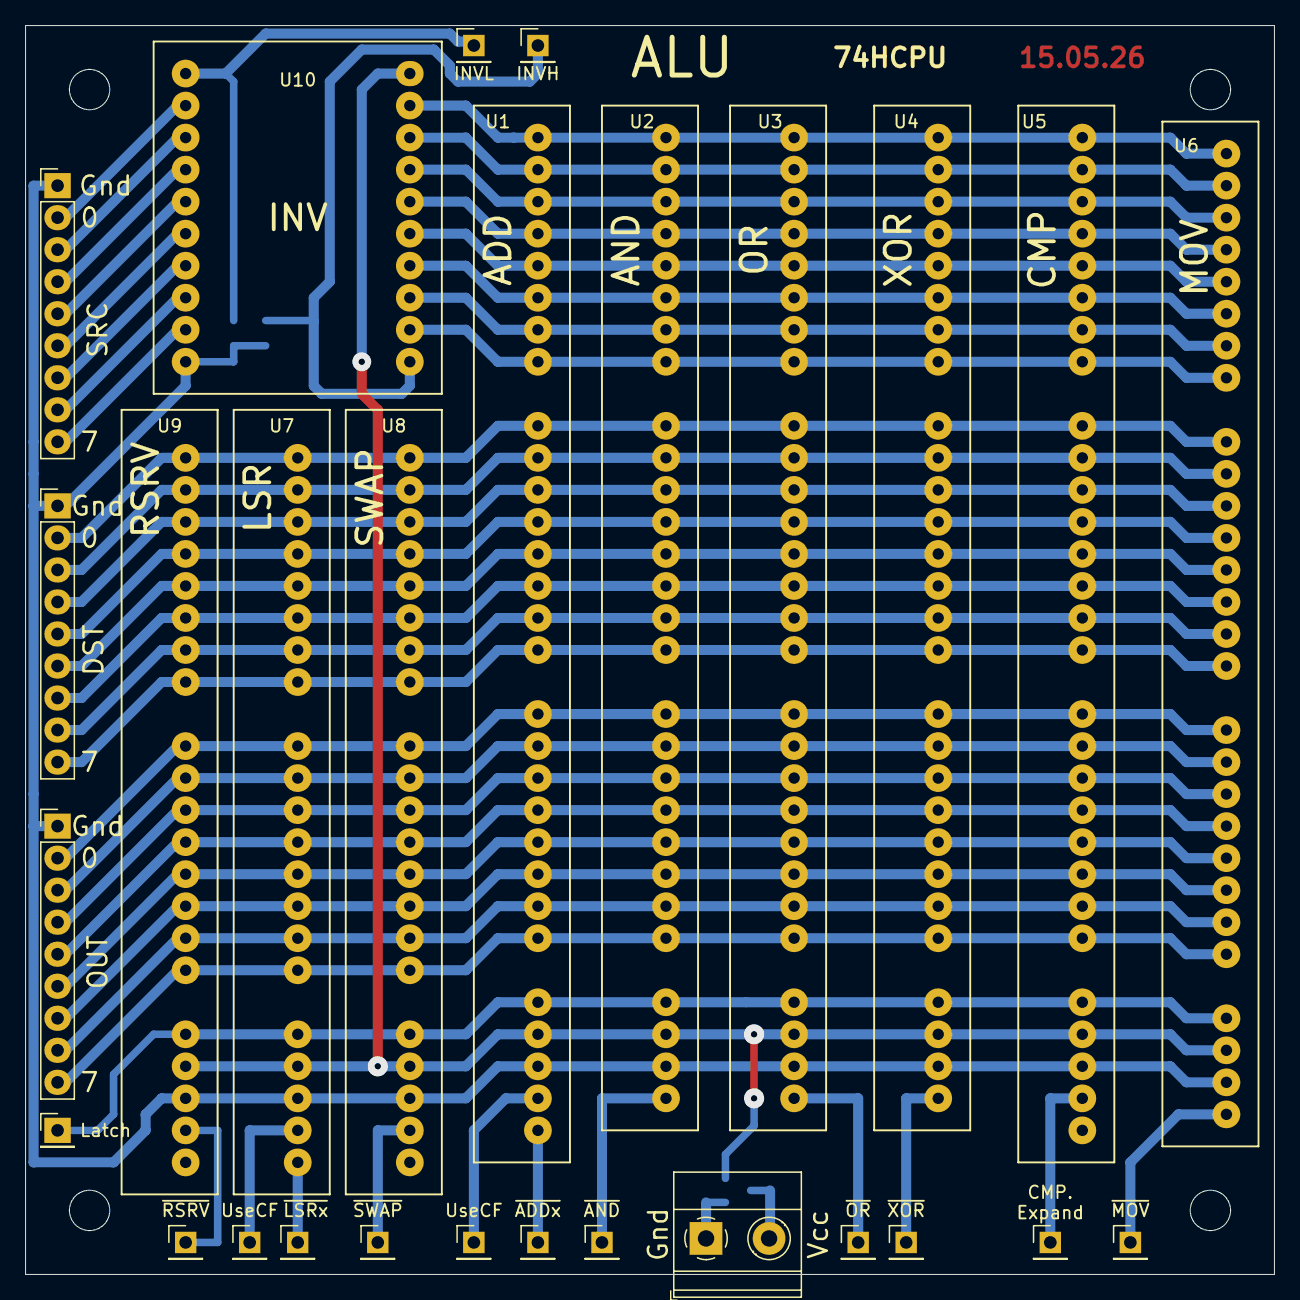
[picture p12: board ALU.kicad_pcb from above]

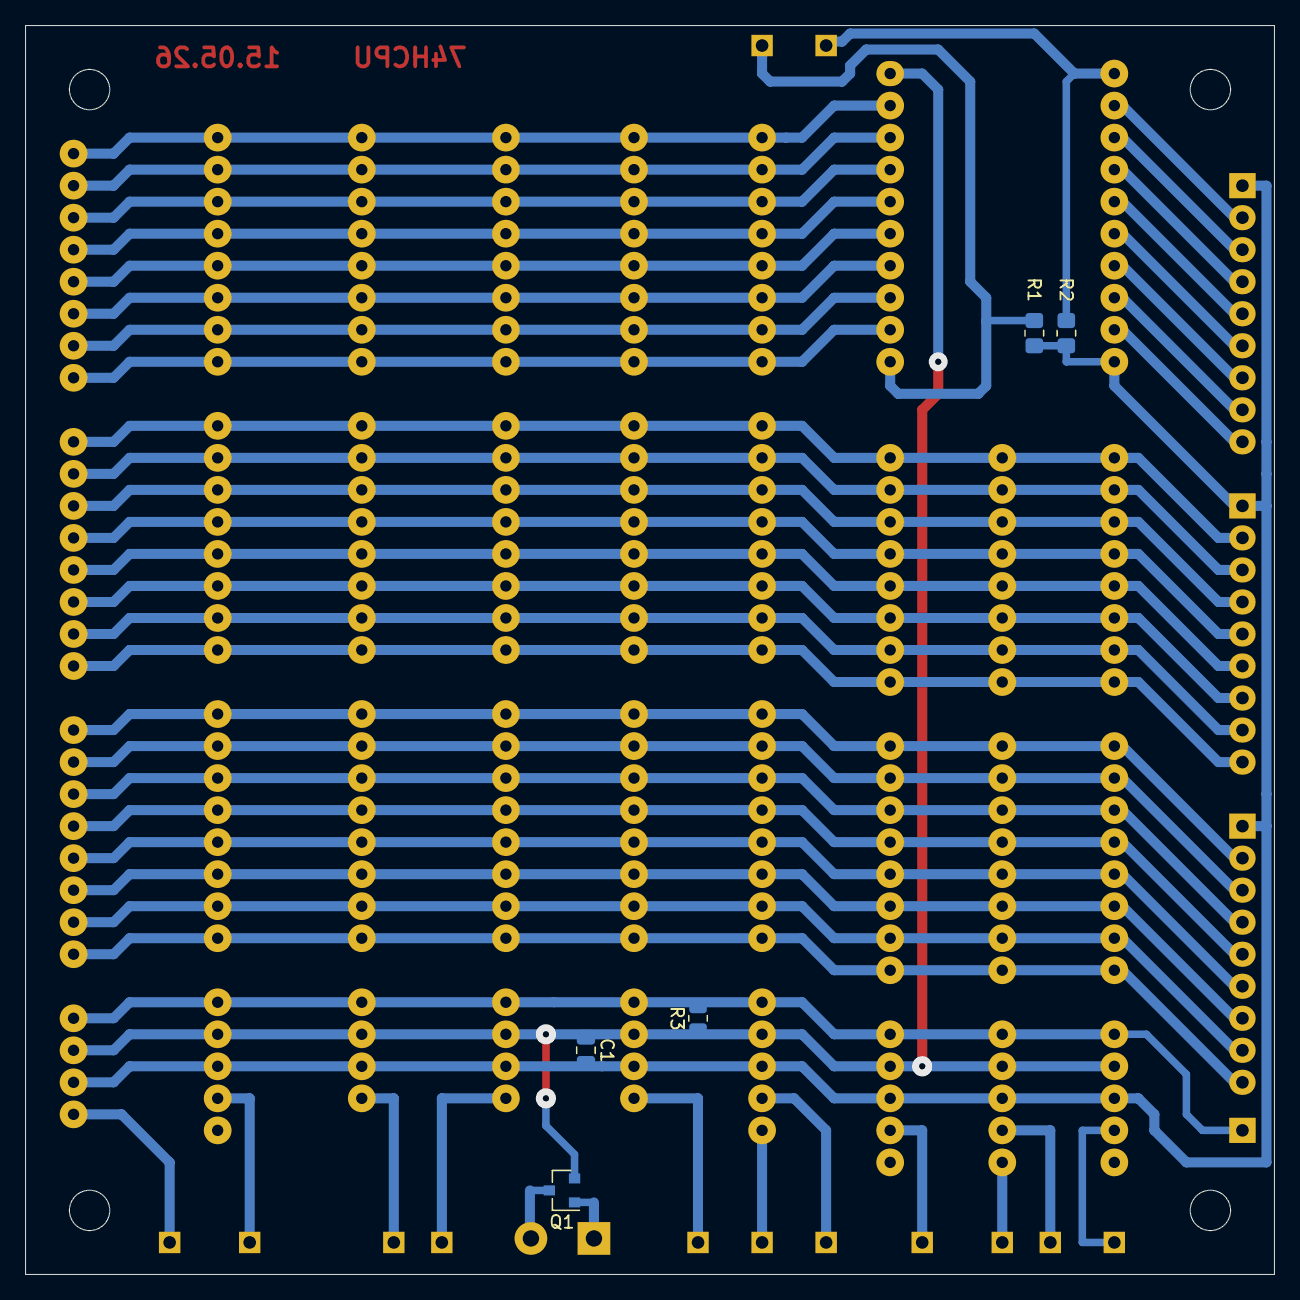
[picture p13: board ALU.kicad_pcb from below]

Board: 2 copper layers, 99.1 x 99.1 mm, 37 parts (5 on the bottom side), 49 nets.

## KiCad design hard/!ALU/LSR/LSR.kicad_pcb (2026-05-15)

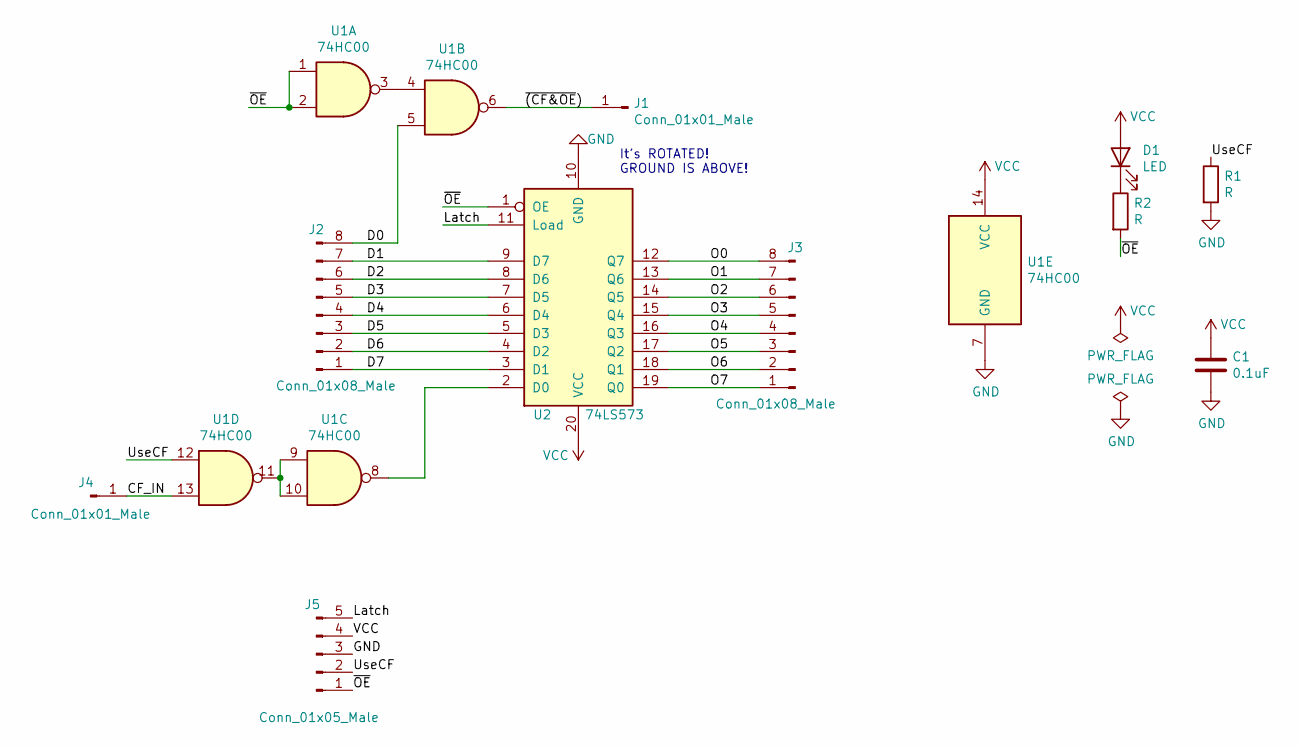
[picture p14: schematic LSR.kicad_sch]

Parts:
C1: 0.1uF; C_0805_2012Metric_Pad1.18x1.45mm_HandSolder
D1: LED; LED_0805_2012Metric_Pad1.15x1.40mm_HandSolder
J1, J4: Conn_01x01_Male; PinHeader_1x01_P2.54mm_Vertical
J2, J3: Conn_01x08_Male; PinHeader_1x08_P2.54mm_Horizontal
J5: Conn_01x05_Male; PinHeader_1x05_P2.54mm_Horizontal
R1, R2: R; R_0805_2012Metric_Pad1.20x1.40mm_HandSolder
U1: 74HC00; SO-14_3.9x8.65mm_P1.27mm
U2: 74LS573; SOIC-20W_7.5x12.8mm_P1.27mm

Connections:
/CF_IN: J4.1, U1.13
/D0: J2.8, U1.5
/D1: J2.7, U2.9 (D7)
/D2: J2.6, U2.8 (D6)
/D3: J2.5, U2.7 (D5)
/D4: J2.4, U2.6 (D4)
/D5: J2.3, U2.5 (D3)
/D6: J2.2, U2.4 (D2)
/D7: J2.1, U2.3 (D1)
/Latch: J5.5, U2.11 (Load)
/O0: J3.8, U2.12 (Q7)
/O1: J3.7, U2.13 (Q6)
/O2: J3.6, U2.14 (Q5)
/O3: J3.5, U2.15 (Q4)
/O4: J3.4, U2.16 (Q3)
/O5: J3.3, U2.17 (Q2)
/O6: J3.2, U2.18 (Q1)
/O7: J3.1, U2.19 (Q0)
/UseCF: J5.2, R1.1, U1.12
/~(CF&OE): J1.1, U1.6
/~OE: J5.1, R2.2, U1.1, U1.2, U2.1 (OE)
GND: C1.2, J5.3, R1.2, U1.7 (GND), U2.10 (GND)
unnamed: D1.1 (K), R2.1
unnamed: U1.3, U1.4
unnamed: U1.8, U2.2 (D0)
unnamed: U1.9, U1.10, U1.11
VCC: C1.1, D1.2 (A), J5.4, U1.14 (VCC), U2.20 (VCC)

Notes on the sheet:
It's ROTATED! GROUND IS ABOVE!

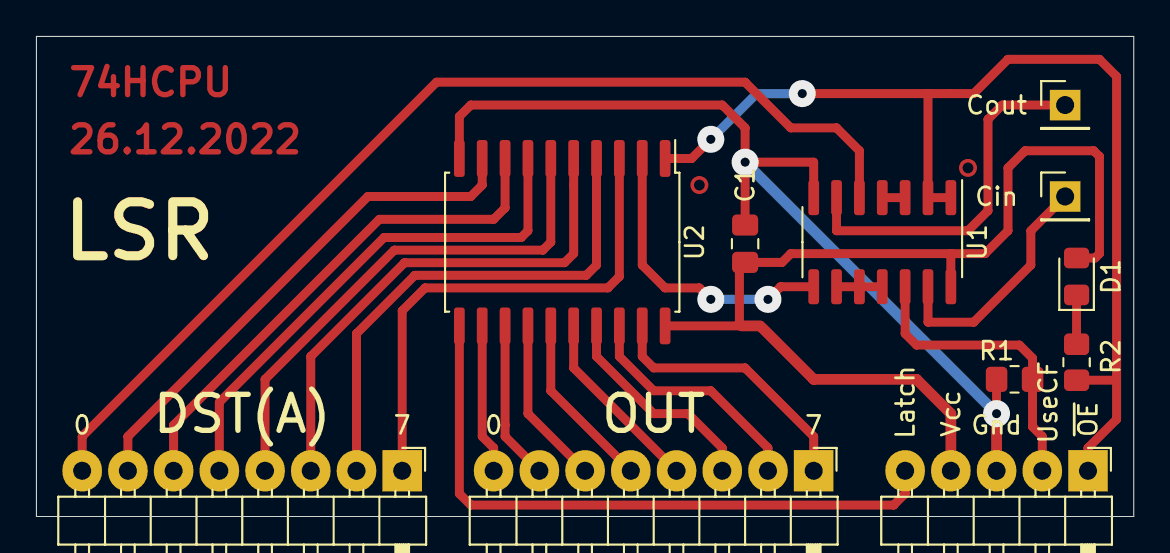
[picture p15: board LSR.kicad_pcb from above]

Board: 2 copper layers, 61.0 x 26.7 mm, 11 parts (0 on the bottom side), 27 nets.

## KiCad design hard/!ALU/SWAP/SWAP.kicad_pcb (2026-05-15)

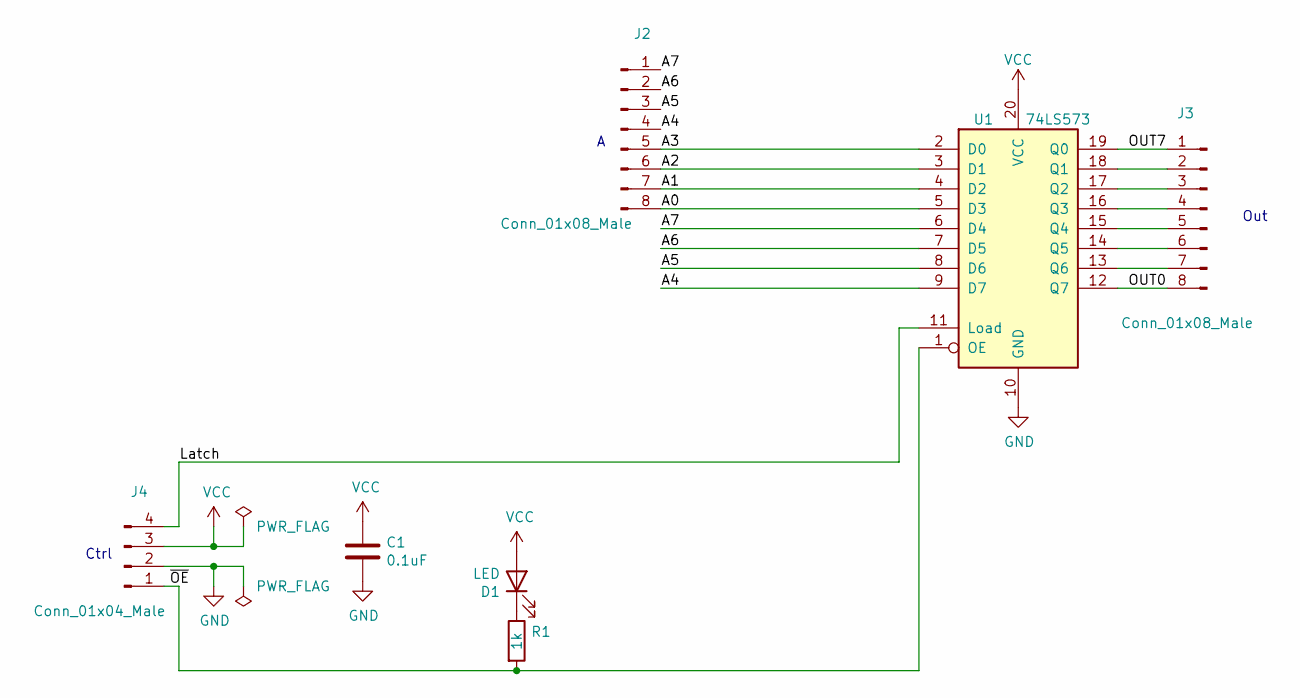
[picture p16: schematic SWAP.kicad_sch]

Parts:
C1: 0.1uF; C_0805_2012Metric_Pad1.18x1.45mm_HandSolder
D1: LED; LED_0805_2012Metric_Pad1.15x1.40mm_HandSolder
J2, J3: Conn_01x08_Male; PinHeader_1x08_P2.54mm_Horizontal
J4: Conn_01x04_Male; PinHeader_1x04_P2.54mm_Horizontal
R1: 1k; R_0805_2012Metric_Pad1.20x1.40mm_HandSolder
U1: 74LS573; SOP-20_7.5x12.8mm_P1.27mm

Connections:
/A0: J2.8, U1.5 (D3)
/A1: J2.7, U1.4 (D2)
/A2: J2.6, U1.3 (D1)
/A3: J2.5, U1.2 (D0)
/A4: J2.4, U1.9 (D7)
/A5: J2.3, U1.8 (D6)
/A6: J2.2, U1.7 (D5)
/A7: J2.1, U1.6 (D4)
/Latch: J4.4, U1.11 (Load)
/OUT0: J3.8, U1.12 (Q7)
/OUT7: J3.1, U1.19 (Q0)
/~OE: J4.1, R1.2, U1.1 (OE)
GND: C1.2, J4.2, U1.10 (GND)
unnamed: D1.1 (K), R1.1
unnamed: J3.2, U1.18 (Q1)
unnamed: J3.3, U1.17 (Q2)
unnamed: J3.4, U1.16 (Q3)
unnamed: J3.5, U1.15 (Q4)
unnamed: J3.6, U1.14 (Q5)
unnamed: J3.7, U1.13 (Q6)
VCC: C1.1, D1.2 (A), J4.3, U1.20 (VCC)

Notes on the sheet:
Out
Ctrl

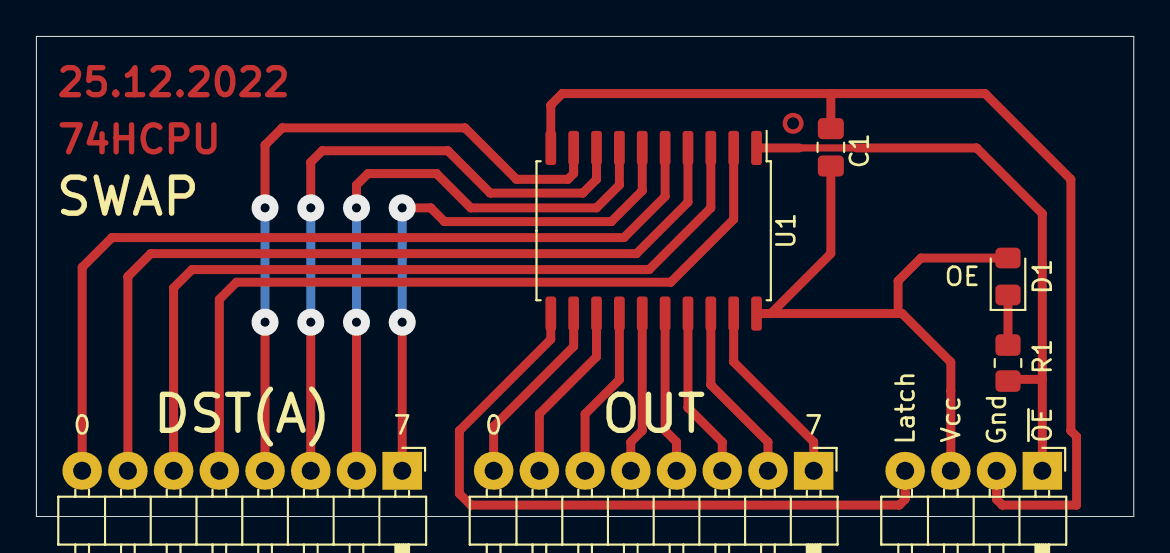
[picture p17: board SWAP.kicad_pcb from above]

Board: 2 copper layers, 61.0 x 26.7 mm, 7 parts (0 on the bottom side), 21 nets.

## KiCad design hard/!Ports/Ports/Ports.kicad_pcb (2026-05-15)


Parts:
C1, C2, C3: 0.1uF; C_Axial_L3.8mm_D2.6mm_P22.86mm_Horizontal
C4: 0.1uF; C_Disc_D7.0mm_W2.5mm_P5.00mm
D1, D2, D3, D4, D5, D6, D7, D8, D9, D10: LED; LED_Rectangular_W5.0mm_H2.0mm
D11, D12, D13, D14, D15, D16, D17, D18, D19, D20, D21, D22, D23, D24, D25, D26: 6x6-tact-btn; SW_PUSH_6mm_H4.3mm
D27, D28: 1N4148; D_DO-35_SOD27_P10.16mm_Horizontal
DS1: WC1602A; WH1602-2-holes
H1, H2, H3, H4, H5, H6, H7, H8: MountingHole; MountingHole_3.2mm_M3
J1, J2, J3, J6: Conn_01x09_Male; PinHeader_1x09_P2.54mm_Vertical
J4: Screw_Terminal_01x02; TerminalBlock_Phoenix_PT-1,5-2-5.0-H_1x02_P5.00mm_Horizontal
J5: Conn_01x04_Male; PinHeader_1x04_P2.54mm_Vertical
J7, J9: Conn_01x02_Male; PinHeader_1x02_P2.54mm_Vertical
J8: Conn_01x08_Male; PinHeader_1x08_P2.54mm_Vertical
JP1: Jumper; SolderJumper-2_P1.3mm_Open_RoundedPad1.0x1.5mm
Q1: IRLML2060; SOT-23
Q2: IRLML5203; SOT-23
R1: 20; R_Axial_DIN0207_L6.3mm_D2.5mm_P15.24mm_Horizontal
R2, R3, R14, R15, R16, R17, R18, R19, R20, R21, R22: 10k; R_0805_2012Metric_Pad1.20x1.40mm_HandSolder
R4, R5, R6, R7, R8, R9, R10, R11, R12, R13: 1k; R_0805_2012Metric_Pad1.20x1.40mm_HandSolder
RV1: R_POT; pot-5x5
U1, U2, U3: 74LS574; DIP-20_W7.62mm

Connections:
/BUS0: J6.2, U3.12 (Q7)
/BUS1: J6.3, U3.13 (Q6)
/BUS2: J6.4, U3.14 (Q5)
/BUS3: J6.5, U3.15 (Q4)
/BUS4: J6.6, U3.16 (Q3)
/BUS5: J6.7, U3.17 (Q2)
/BUS6: J6.8, U3.18 (Q1)
/BUS7: J6.9, U3.19 (Q0)
/D0: DS1.7 (D0), J1.2, R4.2, U1.2 (D0), U2.2 (D0)
/D1: DS1.8 (D1), J1.3, R5.2, U1.3 (D1), U2.3 (D1)
/D2: DS1.9 (D2), J1.4, R6.2, U1.4 (D2), U2.4 (D2)
/D3: DS1.10 (D3), J1.5, R7.2, U1.5 (D3), U2.5 (D3)
/D4: DS1.11 (D4), J1.6, R8.2, U1.6 (D4), U2.6 (D4)
/D5: DS1.12 (D5), J1.7, R9.2, U1.7 (D5), U2.7 (D5)
/D6: DS1.13 (D6), J1.8, R11.2, U1.8 (D6), U2.8 (D6)
/D7: DS1.14 (D7), J1.9, R13.2, U1.9 (D7), U2.9 (D7)
/IN0.0: D25.1, D26.1, J8.8, R21.1, U3.9 (D7)
/IN0.1: D23.1, D24.1, J8.7, R20.1, U3.8 (D6)
/IN0.2: D21.1, D22.1, J8.6, R19.1, U3.7 (D5)
/IN0.3: D19.1, D20.1, J8.5, R18.1, U3.6 (D4)
/IN0.4: D17.1, D18.1, J8.4, R17.1, U3.5 (D3)
/IN0.5: D15.1, D16.1, J8.3, R16.1, U3.4 (D2)
/IN0.6: D13.1, D14.1, J8.2, R15.1, U3.3 (D1)
/IN0.7: D11.1, D12.1, J8.1, R14.1, U3.2 (D0)
/IN0.C: J7.1, U3.11 (Cp)
/IN0.OE: J7.2, U3.1 (OE)
/OUT0: J5.4, R2.1, U1.11 (Cp)
/OUT1: J5.2, R3.1, U2.11 (Cp)
/OUT2: DS1.6 (E), J5.1, R10.2
/P0.0: DS1.4 (RS), J2.2, R12.2, U1.19 (Q0)
/P0.1: J2.3, U1.18 (Q1)
/P0.2: J2.4, U1.17 (Q2)
/P0.3: J2.5, U1.16 (Q3)
/P0.4: J2.6, U1.15 (Q4)
/P0.5: D27.1 (K), J2.7, U1.14 (Q5)
/P0.6: D28.1 (K), J2.8, U1.13 (Q6)
/P0.7: J2.9, Q1.1 (G), R22.1, U1.12 (Q7)
/P1.0: J3.2, U2.19 (Q0)
/P1.1: J3.3, U2.18 (Q1)
/P1.2: J3.4, U2.17 (Q2)
/P1.3: J3.5, U2.16 (Q3)
/P1.4: J3.6, U2.15 (Q4)
/P1.5: J3.7, U2.14 (Q5)
/P1.6: J3.8, U2.13 (Q6)
/P1.7: J3.9, U2.12 (Q7)
GND: C1.2, C2.2, C3.2, C4.2, DS1.1 (VSS), DS1.5 (R/W), J1.1, J2.1, J3.1, J4.1, J5.3, J6.1, J9.1, J9.2, JP1.2, Q1.2 (S), Q2.1 (G), R2.2, R3.2, R22.2, RV1.1, U1.1 (OE), U1.10 (GND), U2.1 (OE), U2.10 (GND), U3.10 (GND)
unnamed: D1.1 (K), D2.1 (K), D3.1 (K), D4.1 (K), D5.1 (K), D6.1 (K), D7.1 (K), D8.1 (K), D9.1 (K), D10.1 (K), JP1.1
unnamed: D1.2 (A), R4.1
unnamed: D2.2 (A), R5.1
unnamed: D3.2 (A), R6.1
unnamed: D4.2 (A), R7.1
unnamed: D5.2 (A), R8.1
unnamed: D6.2 (A), R9.1
unnamed: D7.2 (A), R10.1
unnamed: D8.2 (A), R11.1
unnamed: D9.2 (A), R12.1
unnamed: D10.2 (A), R13.1
unnamed: D11.2, D13.2, D15.2, D17.2, D19.2, D21.2, D23.2, D25.2, D27.2 (A)
unnamed: D12.2, D14.2, D16.2, D18.2, D20.2, D22.2, D24.2, D26.2, D28.2 (A)
unnamed: DS1.3 (VO), RV1.2
unnamed: DS1.15 (LED(+)), R1.2
unnamed: DS1.16 (LED(-)), Q1.3 (D)
unnamed: J4.2, Q2.3 (D)
VCC: C1.1, C2.1, C3.1, C4.1, DS1.2 (VDD), Q2.2 (S), R1.1, R14.2, R15.2, R16.2, R17.2, R18.2, R19.2, R20.2, R21.2, RV1.3, U1.20 (VCC), U2.20 (VCC), U3.20 (VCC)

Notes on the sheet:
OUT



Board: 2 copper layers, 99.1 x 99.1 mm, 79 parts (24 on the bottom side), 64 nets.

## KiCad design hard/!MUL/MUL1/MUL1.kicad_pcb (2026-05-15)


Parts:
C1, C2: 0.1uF; C_Disc_D7.5mm_W5.0mm_P10.00mm
J1, J3: Conn_01x08_Male; PinHeader_1x08_P2.54mm_Horizontal
J2: Conn_01x09_Male; PinHeader_1x09_P2.54mm_Horizontal
J4: Conn_01x01_Male; PinHeader_1x01_P2.54mm_Horizontal
J5: Conn_01x02_Male; PinHeader_1x02_P2.54mm_Horizontal
J6: Conn_01x01_Male; PinHeader_1x01_P2.54mm_Vertical
R1: 10k; R_0805_2012Metric_Pad1.20x1.40mm_HandSolder
U1, U3: 74LS08; DIP-14_W7.62mm_Socket
U2, U4: 74LS283; DIP-16_W7.62mm_Socket

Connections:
/A0: J3.8, U1.1
/A1: J3.7, U1.4
/A2: J3.6, U1.9
/A3: J3.5, U1.12
/A4: J3.4, U3.1
/A5: J3.3, U3.4
/A6: J3.2, U3.9
/A7: J3.1, U3.12
/Bi: J4.1, U1.2, U1.5, U1.10, U1.13, U3.2, U3.5, U3.10, U3.13
/P0: J1.8, U2.5 (A1)
/P1: J1.7, U2.3 (A2)
/P2: J1.6, U2.14 (A3)
/P3: J1.5, U2.12 (A4)
/P4: J1.4, U4.5 (A1)
/P5: J1.3, U4.3 (A2)
/P6: J1.2, U4.14 (A3)
/P7: J1.1, U4.12 (A4)
/S0: J2.9, U2.4 (S1)
/S1: J2.8, U2.1 (S2)
/S2: J2.7, U2.13 (S3)
/S3: J2.6, U2.10 (S4)
/S4: J2.5, U4.4 (S1)
/S5: J2.4, U4.1 (S2)
/S6: J2.3, U4.13 (S3)
/S7: J2.2, U4.10 (S4)
/S8: J2.1, U4.9 (C4)
GND: C1.2, C2.2, J5.1, R1.1, U1.7 (GND), U2.8 (GND), U3.7 (GND), U4.8 (GND)
unnamed: J6.1, R1.2, U2.7 (C0)
unnamed: U1.3, U2.6 (B1)
unnamed: U1.6, U2.2 (B2)
unnamed: U1.8, U2.15 (B3)
unnamed: U1.11, U2.11 (B4)
unnamed: U2.9 (C4), U4.7 (C0)
unnamed: U3.3, U4.6 (B1)
unnamed: U3.6, U4.2 (B2)
unnamed: U3.8, U4.15 (B3)
unnamed: U3.11, U4.11 (B4)
VCC: C1.1, C2.1, J5.2, U1.14 (VCC), U2.16 (VCC), U3.14 (VCC), U4.16 (VCC)

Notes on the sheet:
B[i]


Board: 2 copper layers, 83.8 x 36.2 mm, 13 parts (0 on the bottom side), 38 nets.

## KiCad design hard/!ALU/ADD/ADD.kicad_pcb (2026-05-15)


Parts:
C1: 0.1uF; C_0805_2012Metric_Pad1.18x1.45mm_HandSolder
D1: LED; LED_0805_2012Metric_Pad1.15x1.40mm_HandSolder
J1, J2, J3: Conn_01x08_Male; PinHeader_1x08_P2.54mm_Horizontal
J4: Conn_01x05_Male; PinHeader_1x05_P2.54mm_Horizontal
J5, J6, J7: Conn_01x01_Male; PinHeader_1x01_P2.54mm_Vertical
R1: 1k; R_0805_2012Metric_Pad1.20x1.40mm_HandSolder
R2, R3: 10k; R_0805_2012Metric_Pad1.20x1.40mm_HandSolder
U1, U2: 74LS283; DIP-16_W7.62mm
U3: 74LS573; DIP-20_W7.62mm
U4: 74HC00; DIP-14_W7.62mm

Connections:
/A0: J2.8, U1.5 (A1)
/A1: J2.7, U1.3 (A2)
/A2: J2.6, U1.14 (A3)
/A3: J2.5, U1.12 (A4)
/A4: J2.4, U2.5 (A1)
/A5: J2.3, U2.3 (A2)
/A6: J2.2, U2.14 (A3)
/A7: J2.1, U2.12 (A4)
/ADD_CIN: J5.1, U4.2
/B0: J1.8, U1.6 (B1)
/B1: J1.7, U1.2 (B2)
/B2: J1.6, U1.15 (B3)
/B3: J1.5, U1.11 (B4)
/B4: J1.4, U2.6 (B1)
/B5: J1.3, U2.2 (B2)
/B6: J1.2, U2.15 (B3)
/B7: J1.1, U2.11 (B4)
/Latch: J4.5, R2.1, U3.11 (Load)
/O0: J3.8, U3.12 (Q7)
/O1: J3.7, U3.13 (Q6)
/O2: J3.6, U3.14 (Q5)
/O3: J3.5, U3.15 (Q4)
/O4: J3.4, U3.16 (Q3)
/O5: J3.3, U3.17 (Q2)
/O6: J3.2, U3.18 (Q1)
/O7: J3.1, U3.19 (Q0)
/UseCF: J4.1, R3.1, U4.1
/auxiliary_carry: J7.1, U1.9 (C4), U2.7 (C0)
/~(ADD_COUT&OE): J6.1, U4.8
/~OE: J4.2, R1.2, U3.1 (OE), U4.12, U4.13
GND: C1.2, J4.3, R2.2, R3.2, U1.8 (GND), U2.8 (GND), U3.10 (GND), U4.7 (GND)
unnamed: D1.1 (K), R1.1
unnamed: U1.7 (C0), U4.6
unnamed: U1.4 (S1), U3.9 (D7)
unnamed: U1.1 (S2), U3.8 (D6)
unnamed: U1.13 (S3), U3.7 (D5)
unnamed: U1.10 (S4), U3.6 (D4)
unnamed: U2.9 (C4), U4.9
unnamed: U2.4 (S1), U3.5 (D3)
unnamed: U2.1 (S2), U3.4 (D2)
unnamed: U2.13 (S3), U3.3 (D1)
unnamed: U2.10 (S4), U3.2 (D0)
unnamed: U4.3, U4.4, U4.5
unnamed: U4.10, U4.11
VCC: C1.1, D1.2 (A), J4.4, U1.16 (VCC), U2.16 (VCC), U3.20 (VCC), U4.14 (VCC)


Board: 2 copper layers, 83.8 x 39.4 mm, 16 parts (1 on the bottom side), 45 nets.

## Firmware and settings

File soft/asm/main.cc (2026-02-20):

#include <cstdint>
#include <iostream>
#include <vector>

#ifdef _WIN32
#include <windows.h>
#endif

#include "assm.h"

using namespace std;

void help() {
  const char* help_lines[] = {
      "74HCPU assembler v 0.6\n",
      "Support next operations:\n",
      "arithmetic: ADD, ADDC, AND, OR, XOR, MUL, UNO (SWAP, INV, LSR, LSRC), MOV\n",
      "memory: LPM, LD, ST\n",
      "video memory: LDV, STV\n",
      "port: IN, OUT, TOGL\n",
      "compare: CMP, CMPC\n",
      "jmp: CALL, JMP, RET, JZ, JL, JNE, JE, JG, JC, JNZ, JNC, JHC, JNHC, STOP, AFCALL, NOP\n",
      "Registers: R0, R1, R2, R3, R4, R5, R6, R7\n",
      "Register pointers: X(XL+XH), Y(YL+YH), SP(SPL+SPH), V(VL+VH)\n",
      "Auto-increment pointers: Xi, Yi, SPi, Vi\n",
      "Auto-decrement pointers: Xd, Yd, SPd, Vd\n",
      "PORTS: PORT0-31, PIN0-31\n",
      "Macro: LO()/HI() for pointers, for example:\n mov YL, LO(StringName)\n",
      "Macro: L()/H()/~/'/` for registers, for example:\n",
      " ` - invert high nibble, ' - invert low nibble, ~ - invert whole byte\n",
      " L() - use low nibble, H() - use high nibble\n",
      " MOV R0, L(R1) - copy low nibble of R1 into R0\n",
      " MOV R0, `R1 - invert high nibble of R1 and copy both nibbles into R0\n",
      "Directives:\n.org 1000h\n.str S \"Some str\"\n.def FROM TO\n.def FROM(param) TO param, bla-bla\n",
      ".def push(r) ST SPD, r ; example for .def with param\n",
      ".db NAME 123 ; one const in ROM\n",
      ".db ARRAY 1, 2, 3 ; three consts in ROM\n",
      ".db MULTILINE \\ ; const on many lines of source code\n",
      "  1, 2, 3, \\\n",
      "  4, 5, 6\n",
      ".dw PTR NAME ; address of .db NAME 123 (see above)\n",
      "; <- this is comment",
      "\nRun:\n",
      "74hc-asm.exe src.asm [-pre]\n",
      " -pre will print preprocessed src.asm\n",
      "74hc-asm.exe src.asm [-v]\n",
      " -v print more verbose information about src.asm\n",
      "74hc-asm.exe src.asm [out.hex]\n",
      " will create result binary out.hex\n",
      nullptr
  };

  int i = 0;
  while (help_lines[i]) {
    cout << help_lines[i];
    i++;
  }
}

int main(int argc, char* argv[]) {
#ifdef _WIN32
  SetConsoleOutputCP(CP_UTF8);
#endif

  bool show_pre {false};
  bool verbose {false};

  // fill vector
  vector<string> args;
  for (int i = 0; i < argc; i++) {
    if (argv[i] == nullptr)
      continue;

    string arg = argv[i];
    if (arg.size() && arg[0] != '-')
      args.push_back(arg);
    if (arg == "-pre")
      show_pre = true;
    if (arg == "-v")
      verbose = true;
  }

  if (args.size() < 2 || args[1] == "help") {
    help();
    return 0;
  }

  if (verbose) {
    cout << "verbose - on" << endl;
    cout << "remaining args: " << args.size() << endl;
  }

  if (args.size() > 3) {
    cout << "Error! asm require only 3 args: asm_name [asm_file] [hex_file] (and -v, -pre in any place)" << endl;
    return 1;
  }

  try {  // Now args.size() may be equal 2 or 3
    Assembler assm;
    bool res = assm.Process(args[1], show_pre, verbose);
    if (res)
      cout << "*** Can't write code because some errors was found ***" << endl;
    else if (args.size() > 2 && !show_pre)
      assm.WriteBinary(args[2]);
    return res;
  } catch (const char* e) {
    cout << "Error: " << e << endl;
  } catch (std::exception e) {
    cout << "Error: " << e.what() << endl;
  }

  return 0;
}

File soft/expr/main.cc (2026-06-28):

#include "compile.h"
#include "func_guard.h"

#include <iostream>
#include <fstream>
#include <sstream>
#include <string>

using namespace std;

int main(int argc, char* argv[]) {
  FuncGuard fg("main");
  cout << "stack: " << FuncGuard::stack_str() << endl;
  cout << "argc: " << argc << endl;
  for (int i = 0; i < argc; i++)
    cout << "i: " << i << ", arg[i]: " << argv[i] << endl;
  cout << endl;

  int res {0};
  if (argc == 3 && argv[1] && argv[2]) {
    string key(argv[1]);
    if (key == "-f") {
      string fname(argv[2]);
      ifstream f(fname, ios_base::in);
      if (!f) {
        cout << "Can't open input file " << fname << endl;
        return 1;
      }

      stringstream buf;
      buf << f.rdbuf();
      cout << "source code:\n" << buf.str() << endl;
      try {
        Compile(buf.str());
      } catch (const std::exception& e) {
        cout << "Compile error: " << e.what() << endl;
      }
    }
  } else if (argc == 2 && argv[1]) {
    cout << "Try to process: \"" << argv[1] << "\"" << endl;
    try {
      res = Compile(argv[1]);
    } catch (const std::exception& e) {
      cout << "Compile error: " << e.what() << endl;
    }
  } else {
    cout << "Using: simple_expr.exe \"1+2+3;\"" << endl;
    return 1;
  }

  cout << "main finished" << endl;
  return res;
}

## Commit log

2025-11-16 Polishing address printing
2025-11-17 Other way to print ptrs
2025-11-19 Polishing stack printing
2025-11-21 Replace switch to inheritance
2025-11-26 Print labels near IP address...
2025-11-27 KiCAD 5 -> 9
    [MUX16bit.kicad_pcb, MUX16bit.kicad_sch]
2025-12-02 Polishing asm printing
2025-12-10 Rename fields to lower case
2025-12-26 A new stage of processor creation has begun!
2026-01-02 Remove duplicate test case
2026-01-09 Fix label name
    [Regs-v6-B_Cu.gbr, Regs-v6-B_Mask.gbr, Regs-v6-B_Silkscreen.gbr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]
2026-01-10 Add update timer to video.dump drawer
2026-01-23 Fix description & version of ASM!
    [main.cc]
2026-02-15 Cleanup. Remove OCC from PrintCode
2026-02-15 Try to print consts tables with addresses:
2026-02-20 Lost error that needs to be printed
    [main.cc]
2026-02-20 Bugfixing. Have to print also warning and messages
2026-02-21 Will use SlotAllocator, Assembler will delegate some methods to it
2026-02-21 Just prototype of template
2026-02-21 Polishing SlotAllocator
2026-02-22 Regs v6.1
    [Regs-v6.kicad_pcb, Regs-v6.kicad_sch]
2026-02-23 Regs v6.1 in work
    [Regs-v6.kicad_pcb]
2026-03-01 if -> switch
2026-03-03 Replace if to switch
2026-03-07 Continue to replace GetToken to currentToken
2026-03-08 Polishing printing. Add empty module for optimization
2026-03-10 Regs-v6.1 in work
    [Regs-v6.kicad_pcb]
2026-03-13 Fix bug with lost operation. Add logs.
    [main.cc]
2026-03-14 Added print error.
2026-03-14 Try to print better
2026-03-15 Workin on tree print
2026-03-15 Debugging print_tree
2026-03-18 Regs v6.1 is almost ready!
    [Regs-v6.kicad_pcb]
2026-03-19 Regs v6.1 is ok
    [Regs-v6-B_Cu.gbr, Regs-v6-B_Mask.gbr, Regs-v6-B_Paste.gbr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]
2026-03-25 MUX8x1-1bit v2
    [MUX8x1-1bit.kicad_pcb, MUX8x1-1bit.kicad_sch, MUX8x1-1bit.sch]
2026-03-26 MUX8x1-1bit v2 is finished
    [MUX8x1-1bit.kicad_pcb]
2026-03-27 Some problem with this files
    [MUX8x1-1bit.kicad_pcb, MUX8x1-1bit.kicad_sch, MUX8x1-1bit.sch]
2026-03-27 MUX8x1-1bit v2 is almost ready
    [MUX8x1-1bit.kicad_pcb]
2026-03-27 Polishing PCB. Make new gerbers
    [MUX8x1-1bit-B_Cu.gbr, MUX8x1-1bit-B_Mask.gbr, MUX8x1-1bit-B_Paste.gbr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]
2026-03-27 Just move MUX PCB to subfolder
    [MUX8x1-1bit-B_Cu.gbr, MUX8x1-1bit-B_Mask.gbr, MUX8x1-1bit-B_Paste.gbr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]
2026-03-27 Update gerbers
    [MUX8x1-1bit-B_Cu.gbr, MUX8x1-1bit-B_Mask.gbr, MUX8x1-1bit-B_Paste.gbr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]
2026-03-27 End Plate PCB for Registers
    [EndPlate.kicad_pcb, EndPlate.kicad_sch]
2026-03-28 MUX8x1-1bit v2 rework
    [MUX8x1-1bit-B_Cu.gbr, MUX8x1-1bit-B_Mask.gbr, MUX8x1-1bit-B_Paste.gbr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]
2026-03-28 End Plate PCB in work
    [EndPlate.kicad_pcb, EndPlate.kicad_sch]
2026-03-30 MUX8x1-1bit v2 is ready
    [MUX8x1-1bit-B_Cu.gbr, MUX8x1-1bit-B_Mask.gbr, MUX8x1-1bit-B_Paste.gbr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]
2026-03-30 End Plate: make a circuit corresponding to the multiplexers
    [EndPlate.kicad_sch]
2026-03-30 End Plate in work
    [EndPlate.kicad_pcb, EndPlate.kicad_sch]
2026-03-30 End Plate polishing
    [EndPlate.kicad_pcb]
2026-03-30 Move gerbers to subfolder
    [EndPlate-B_Cu.gbr, EndPlate-B_Mask.gbr, EndPlate-B_Paste.gbr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]
2026-03-31 Some file from MUX8x1-1bit pcb
2026-04-02 Fix build. Move fuction to class in expr
    [assemble.cc]
2026-04-05 Rename assemble.* -> backend.*
2026-04-05 Rename Assemble -> GenerateCode
2026-04-10 Swap instruction and comment
    [backend.cc]
2026-04-10 Now source code is printed as comment after instruction
2026-04-11 Bugfixing in Spill method
    [regs_bank.cc]
2026-04-12 Fix printing unary node
2026-04-13 Polishing printing live variables. Remove comments
2026-04-17 EndPlate pcb polishing
    [EndPlate-B_Cu.gbr, EndPlate-B_Mask.gbr, EndPlate-B_Paste.gbr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]
2026-05-01 Fix silk
    [MUL8x8.kicad_pcb]
2026-05-01 Cut EndPlate PCB
    [EndPlate.kicad_pcb]
2026-05-01 MUX8x1 gerbers
    [MUX8x1-1bit-B_Cu.gbr, MUX8x1-1bit-B_Mask.gbr, MUX8x1-1bit-B_Paste.gbr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]
2026-05-02 EndPlate gerbers
    [EndPlate-B_Cu.gbr, EndPlate-B_Mask.gbr, EndPlate-B_Silkscreen.gbr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]
2026-05-02 MUX8x1-1bit gerbers
    [MUX8x1-1bit-B_Cu.gbr, MUX8x1-1bit-B_Mask.gbr, MUX8x1-1bit-B_Paste.gbr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]
2026-05-03 Switch columns in table
2026-05-04 File is not required
    [EndPlate-job.gbrjob]
2026-05-04 Try to create SMD version of MUL1
    [MUL1.dsn, MUL1.kicad_pcb, MUL1.kicad_sch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]
2026-05-06 2 DIP and 2 SO!
    [MUL1.dsn, MUL1.kicad_pcb, MUL1.kicad_sch]
2026-05-13 Bugfixing. Should use one instruction with immediate instead of two instructions
    [backend.cc]
2026-05-14 Some lost file from AND_SMD pcb
2026-05-14 Some lost file from ADD pcb
2026-05-15 Polishing MUL
    [MUL8x8-B_Cu.gbr, MUL8x8-B_Mask.gbr, MUL8x8-B_Silkscreen.gbr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]
2026-05-15 Polishing ADD
    [ADD-B_Cu.gbl, ADD-B_Mask.gbs, ADD-B_Silkscreen.gbo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]
2026-05-15 Polishing MUL1
    [MUL1-B_Cu.gbr, MUL1-B_Mask.gbr, MUL1-B_Silkscreen.gbr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]
2026-05-15 ALU in work
    [ALU.kicad_pcb]
2026-05-15 Replace AND/OR/XOR/MOV on proper symbol
    [ALU.kicad_pcb, ALU.kicad_sch]
2026-05-15 Polishing ALU
    [ALU.kicad_pcb]
2026-05-24 Line on Silk is not required!
    [MUX8x1-1bit-B_Cu.gbr, MUX8x1-1bit-B_Mask.gbr, MUX8x1-1bit-B_Paste.gbr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]
2026-05-27 Fix storing of is_num flag
    [backend.cc]
2026-06-17 make the print narrower
2026-06-23 Fix printing. Add unit test for address_of
2026-06-25 Fix printing AST
2026-06-27 Rename params, fix cmnt string
    [backend.cc]
